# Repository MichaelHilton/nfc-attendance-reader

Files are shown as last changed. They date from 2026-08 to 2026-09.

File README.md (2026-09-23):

# NFC Attendance Reader

A classroom attendance reader: students tap their 13.56 MHz university ID card on a
desktop device, which shows their name, beeps, and logs attendance to an SD card.
Registration and grading happen on the instructor's laptop. Card numbers are never
stored in plain text, and there's no cloud service involved -- everything stays on
the device's SD card and your laptop.

Built for a Canvas classroom, but the pieces are separable: the reader/registration
system has no LMS dependency, and only `software/build_gradebook.py` knows about
Canvas specifically (see `docs/DESIGN_NOTES.md` Section 7).

## Hardware
- **ESP32-3248S035C** ("Cheap Yellow Display" / CYD, 3.5" ST7796 screen, WiFi, SD)
- **PN532** NFC reader over I2C (CN1: 3V3, GND, SDA=IO21, SCL=IO22; DIP switches = I2C)
- 20 mm speaker on the SPEAK connector (GPIO26)
- LiPo battery + USB-C charge/boost module (V713), power switch, all in a 3D-printed case
- Registration reader (laptop): a USB keyboard-wedge NFC reader that types the card number

## Folder layout
- **case/** — 3D-printable enclosure
  - `case_body.stl`, `case_lid.stl`, `case_stand.stl` — print these (PLA/PETG, 0.2 mm, no supports)
  - `case_gen.py` — parametric source (all dimensions at the top; regenerates the STLs)
  - `case_notes.md` — assembly, wiring, print settings, and every adjustable parameter
- **firmware/** — Arduino sketches for the CYD
  - `attendance_reader_PN532/` — the main sketch (open this folder in Arduino IDE)
  - `diagnostics/` — `i2c_scan`, `pn532_test`, `speaker_test` for bring-up/troubleshooting
  - `setup-arduino.sh` / `flash.sh` — install arduino-cli + the ESP32 core, then compile/flash from the command line
- **software/** — laptop-side Python (needs `pip install cryptography pyserial`)
  - `attendance_crypto.py` — shared crypto (keys, tokens, name encryption)
  - `register_cards.py` — registration station GUI → builds encrypted `roster.csv`, and appends each new card to `registration_log.csv`
  - `decode_attendance.py` — turns logged tokens back into AndrewIDs
  - `build_gradebook.py` — fills a Canvas attendance column (Present/Late/Absent) from the log
  - `recover_sessions.py` — dates the `unsynced-<millis>` rows of a log whose clock never synced
  - `reader_test.py` — shows exactly what the USB registration reader types
  - `sd_download.py` — pulls `attendance.csv`/`roster.csv` off the device over USB serial
  - `sd_upload.py` — pushes a new `roster.csv` to the device over USB serial (no SD card removal)
  - `aliases.csv` (copy from `aliases.csv.example`) — `typed_value,sis_login_id` fixups for AndrewIDs/names that don't match Canvas
  - `serial_bridge_host.sh` / `serial_bridge.sh` — bridge the board's USB serial port into the dev container (`SERIAL_BRIDGE.md`)

## How the pieces fit
1. **Generate the key (once):** `python3 software/attendance_crypto.py` → creates
   `secret.key` (keep private!) and writes `secret_key.h` straight into
   `firmware/attendance_reader_PN532/` — nothing to paste, and it's gitignored.
2. **Flash the device:** copy `wifi_config.h.example` to `wifi_config.h` in that same
   folder and fill in your network, then upload the sketch. The Serial Monitor should
   print `crypto self-test: HMAC OK, AES OK`.
3. **Register students:** `python3 software/register_cards.py` — each student taps and
   types their AndrewID (2-8 characters) → writes `roster.csv` (only `token,encrypted_name`)
   and logs when each new card was registered in `registration_log.csv`. Get it onto the
   device either by copying the file to the SD card, or — with the device still plugged
   in — `python3 software/sd_upload.py roster.csv` (sends it over USB; the device swaps
   it in and reloads without a reboot).
4. **In class:** the device reads cards, shows the AndrewID, logs `timestamp,token` to the SD
   (WiFi sets the clock over NTP; no cloud).
5. **Grade:** pull the log with `sd_download.py`, then run `build_gradebook.py` with the
   session date/time and the Canvas column to fill — it matches each AndrewID to a Canvas
   student by SIS Login ID and writes a Canvas-importable CSV (Present/Late/Absent,
   absent = 0). Students who registered a card that day but never tapped are credited
   from their registration time. `decode_attendance.py` gives a plain AndrewID+times list
   if you just want to read the log. If the clock never synced (every row
   `unsynced-…`), date the rows first with `recover_sessions.py` (TESTING_GUIDE Step 7).

Example gradebook run:
```
python3 software/build_gradebook.py --canvas Grades.csv --attendance attendance.csv \
    --date 2026-08-25 --start 10:00 --late-after 10 --close 30 --late-frac 0.5 \
    --column "Aug 25 Activity"
```
AndrewIDs match Canvas students by SIS Login ID. Anything that still doesn't match
is reported; pin it once in `aliases.csv` (`typed_value,sis_login_id`) and re-run.

## Dev container vs. host
The repo ships a dev container with the Python deps, arduino-cli and a browser
desktop (noVNC on forwarded port **6080**, password `vscode`) for running
`register_cards.py`. The container **can't see USB**, so flashing and the serial
tools (`sd_download.py`, `sd_upload.py`, `reader_test.py`) run on the host in a
virtualenv at `software/path/to/venv`, or go through the TCP serial bridge in
`software/SERIAL_BRIDGE.md`. Setup and a full "where does each command run" table
are in `docs/TESTING_GUIDE.md` Step 0.

## Security model
- Card numbers are **never** written to disk — only `token = HMAC-SHA256(key, id)`.
- The AndrewID is **AES-256 encrypted**; the device decrypts to display, the SD holds only ciphertext.
- The key lives in the firmware + `secret.key` on your laptop — never on the SD or in the cloud.
- Protects against a lost SD card / copied files. Does not, by itself, stop someone
  dumping the ESP32 flash (that would need flash-encryption + secure-boot).

## Documentation
- `TESTING.md` — how to run the automated test suite (`pytest`) and what each
  test protects; `docs/TESTING_PLAN.md` is the strategy behind it.
- `docs/TESTING_GUIDE.md` — step-by-step walkthrough, key → firmware → register →
  tap → download → gradebook, plus host/container setup, upload troubleshooting, and
  recovering an unsynced log.
- `software/SERIAL_BRIDGE.md` — using the board's serial port from inside the dev container.
- `docs/DESIGN_NOTES.md` — why it's built this way: hardware choices, the card-ID
  format quirks, firmware gotchas, case design, security model, gradebook logic.
- `docs/WIRING.md` — pin-by-pin PN532/SD/speaker connections.
- `docs/BOM.md` — parts list.
- `docs/ROADMAP.md` — current status, known issues, optional hardening.
- `case/case_notes.md` — case assembly and every adjustable print parameter.

## Status
Complete and tested end-to-end: case, firmware (with encryption + NTP, no cloud),
registration, decoding, and Canvas gradebook filling. In use in class, with one open
issue: **the reader isn't yet getting WiFi/NTP in the classroom**, so logs come off
unsynced and are dated with `recover_sessions.py`. The firmware has temporary serial
diagnostics for this (see `docs/ROADMAP.md`). Optional future hardening: ESP32
flash-encryption + secure-boot (see `docs/DESIGN_NOTES.md` Section 6).

## License
MIT — see `LICENSE`. Contributions welcome; see `CONTRIBUTING.md`.

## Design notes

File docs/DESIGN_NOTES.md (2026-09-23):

# Design Notes, Decisions & Lessons Learned

A running record of *why* this project is built the way it is — the dead ends, the
gotchas, and the decisions behind them. The `README.md` covers how to use everything;
this doc is the reasoning and the hard-won lessons. Newest context is folded in
throughout.

---

## 1. Hardware choices

**Controller — ESP32-3248S035C ("Cheap Yellow Display" / CYD, 3.5").**
Chosen because it bundles what the project needs on one cheap board: an ESP32-WROOM-32,
a 3.5" ST7796 touchscreen, WiFi, and a microSD slot, with a built-in rechargeable-battery
path via VIN. Key facts that bit us or mattered later:
- It's an **ESP32-WROOM-32**, *not* an S3 — 4 MB flash, **no PSRAM**, and a **CH340**
  USB-serial chip. The CH340 is why upload speed matters (below).
- Real board dimensions (from the datasheet, measured): **101.5 × 54.9 × 1.6 mm**, with
  ~5 mm of component height on the back and an **85 × 55 mm** glass area. Our first case
  used a wrong width (85.5 mm) and didn't fit — always use the datasheet numbers.
- Free GPIO is scarce; the speaker amp is on **GPIO26**, and the reader uses the **CN1**
  I2C header (**SDA=IO21, SCL=IO22**).

**Reader — PN532 (13.56 MHz NFC), not 125 kHz.**
The whole reason we're on 13.56 MHz: the CMU ID cards are **13.56 MHz**. This was
confirmed with NFC Tools on a phone (same serial twice) and by the card's 7-byte UID.
A 125 kHz reader cannot read these cards. We do **not** use the fobs. The PN532 talks
**I2C** (set its DIP switches to I2C).

**Registration reader — USB keyboard-wedge (BlissKiss, Amazon B0FJ1X7QFJ).**
Despite an online listing describing it as 125 kHz, the actual unit **does read our
13.56 MHz cards**. It acts like a keyboard: on a tap it "types" a number and presses Enter.

---

## 2. The card-ID format saga (important)

The device (PN532) reads the full **7-byte UID**. Example card: `04 95 AA 3A CF 22 90`.

The USB registration reader types **`0984257796`** for that same card. Decoding that:
`0984257796` = `0x3AAA9504` = the **first 4 UID bytes, little-endian** (`04 95 AA 3A` →
`3A AA 95 04`), as a zero-padded 10-digit decimal.

So the two devices see the same card differently. You **cannot** rebuild the full 7-byte
hex from 4 bytes, so we made the **firmware match the reader**: `uidToKey()` takes the
first 4 UID bytes, little-endian, and formats `%010lu`. Both sides now produce the
identical id string, so registration and reading line up. Using 4 bytes is plenty unique
for a class.

**Lesson:** whenever a second reader is involved, test what it actually emits
(`software/reader_test.py`) before assuming a format. The fix was to standardize on the
constrained device's output.

---

## 3. Firmware architecture & gotchas

- **Upload reliability (CH340):** set **Upload Speed = 115200** in the Arduino IDE.
  921600 fails intermittently on the CH340 ("failed to connect / verify flash").
- **Use the Upload arrow, not Debug.** Hitting Debug triggers OpenOCD and an FTDI error.
- **Pick the right port:** `/dev/cu.usbserial-…`, *not* `/dev/cu.debug-console`. Install
  the **CH340 driver** on macOS if the port doesn't appear.
- **PN532 bring-up is flaky right after a reset.** The fix that made it reliable: a
  **retry loop** (call `getFirmwareVersion()` up to ~12× with short delays) before giving
  up, and use `readPassiveTargetID(…, 300)` with a timeout. Removing
  `setPassiveActivationRetries` fixed reads that stopped after the first card.
- **Screen orientation:** the board is mounted **rotated 180°** so the USB cable exits
  low (less strain), so the sketch sets **`tft.setRotation(3)`** to flip the display back.
- **Non-blocking design:** the UI redraws only the center text band (`drawStatus`) and a
  millis timer clears the result (no `delay`), so scanning never stalls.
- **Time & no cloud:** the Google Apps Script upload was removed. WiFi now exists **only to
  set the clock via NTP** (`configTzTime`, TZ = US Eastern). Each tap logs a real local
  `timestamp,token`; before the clock syncs, rows are logged `unsynced-<millis>` and the
  gradebook script skips/flags them.
- **WiFi bring-up diagnostics (temporary).** Because the classroom WiFi hasn't
  connected yet, the sketch has a `DEBUG` block (`wifiScanReport()` at boot,
  `wifiDiagTick()` in `loop()`) that prints visible networks and the WiFi/NTP status
  over serial. The ESP32 is **2.4 GHz only**, so a 5 GHz-only network or an iPhone
  hotspot without *Maximize Compatibility* shows as `NO_SSID_AVAIL`. Remove the block
  once WiFi works.
- **Two different CSV files, don't confuse them:** `roster.csv` (the id/token → name
  lookup you build) vs `attendance.csv` (the log the device writes). Editing the wrong
  one is an easy mistake — names come from **roster.csv**.
- **Diagnostics exist for a reason:** `firmware/diagnostics/i2c_scan` (PN532 should appear
  at `0x24`), `pn532_test`, and `speaker_test` isolate wiring/library problems fast.
- **Library note:** the reader uses **Adafruit PN532 + Adafruit BusIO**. An earlier
  RDM6300 approach was abandoned (wrong frequency; its library wasn't in Library Manager).

---

## 4. Case design (parametric, `case/case_gen.py`)

The case is generated in Python (trimesh + manifold3d + shapely), not OpenSCAD (not
available in our tooling). Every dimension is a variable at the top of `case_gen.py`;
re-run it to regenerate the three STLs. `case_notes.md` lists all adjustables.

Hard-won lessons:
- **Print orientation drives everything.** The body prints **front-face-down** for a crisp
  bezel. That means *every feature on the front face is a recess that must bridge*. A big
  recess sags.
  - The original **"TAP" marker was a 34 mm filled recess** with raised letters floating
    in it → the floor bridged 34 mm and **sagged, melting into the letters**. Fixed by
    making the ring a **thin groove** and the **"TAP" text engraved** (debossed) — small
    bridges print clean. Paint-fill the engraving for contrast.
- **Mounting:** the glass **drops into the front opening** and rests on side lips; the PCB
  is held forward by that lip and backward by **four press-pads on the lid**. The lid is
  held by **four M3 screws** (2 top, 2 bottom) — an earlier snap lip was too fragile, so we
  raised the top blank strip (`top_bez`) to house the top screw bosses.
- **USB slot** went through several tries: wrong side, wrong size, then correct after
  accounting for the 180° board rotation → **bottom-left, sized ~13 × 8 mm** to clear a
  chunky cable boot.
- **PN532 pocket** sits in the tap zone behind the "TAP" ring, antenna facing out, held by
  snap clips + a wire notch. **Speaker** is a round pocket + round grille on the left with
  a wire gap in the ring.
- **Battery bay:** the back was deepened (`back_gap`) into a bay. The **LiPo tapes into a
  corral on the lid**, *not* against the board's back (avoids shorting/puncturing the pouch
  on the pins).

**Charge-module cradle — the fiddly part.** The V713 charge board is **30 × 20 × 4 mm**.
The tap-zone front is full (PN532 fills it; only ~28 mm free to its right — too narrow for
a 30 mm board), so the cradle went **on the lid** instead, in the lower half. It must stand
the board **upright (20 wide × 30 tall)** so the **USB-C short edge lines up with the
bottom-wall hole**. A **peek slot** in the lid shows the charge LEDs — they're in the
board's **top-right corner (1 mm from the right edge, 4–9 mm from the top)**, so mount the
board **LED-side toward the lid**.

**Power switch mounting.** The slide switch is **19 mm long, mounting holes 15 mm apart,
inline, 3 mm holes** → use **M2.5 self-tapping screws (~5–6 mm)** into the **1.9 mm printed
pilots** on two posts. The switch first **collided with a lid press-pad**; rather than move
the pad, we **centered the switch on the right edge between the two right-side pads**.

**General:** always dry-fit and check clearances against the *other* part (lid features vs
body features), since collisions only appear when assembled. Flat gray renders don't show
shallow relief — preview STLs in a slicer with lighting.

---

## 5. Power & charging

- Corded **USB-C charging** via the V713 module. Its pads: **"5V + / −" = OUTPUT**
  (→ CYD **VIN + GND** on the P1 header, through the switch); plain **"+ / −" = BATTERY**
  (→ LiPo). Verify with a multimeter before connecting the CYD (~5 V on the 5V pads,
  ~3.7–4.2 V on the battery pads).
- The **switch** is inline on the 5 V output (the budget module has no enable pin).
- **Charge from the bottom USB-C only** — that's the module. The CYD's own micro-USB (left
  edge) is the *programming* port and does not charge the battery.
- The module is a power-bank-style IC (has a boost inductor), so it generally charges while
  running; if it ever misbehaves plugged in, switch off and charge. **Never** feed the
  CYD's USB and VIN at the same time.
- Charge-status LEDs are inside — hence the lid peek slot (§4).

**TODO — on-screen battery indicator (not yet possible with this wiring).** The V713
module boosts the LiPo to a regulated ~5 V into `VIN`, so the ESP32 sees the same
voltage whether the cell is full or nearly flat — there is nothing to measure at
`VIN`, and the cheap module exposes no charge-status line. Adding a battery gauge to
the top status bar (`drawTopBar()` in the sketch) needs a hardware change, either:
  - a wire from the raw LiPo **+** through a 2×100 kΩ divider into a free **ADC1** GPIO
    (ADC2 is dead while WiFi is on; confirm a genuinely free ADC1 pin against the
    ESP32-3248S035C schematic — GPIO35 on the CN1/P3 header, input-only, is the usual
    candidate), then map ~3.3–4.2 V to a rough percentage (nonlinear, ±10–20%); or
  - a **MAX17048** I²C fuel gauge on the existing PN532 bus (IO21/IO22) for true
    state-of-charge, ~$5.
  Until one of those is added, the firmware deliberately has no battery UI.

---

## 6. Security design (keep card numbers out of plain text)

**The core insight:** "just encrypt the IDs" fails for two reasons at once — the device
must still *match* a tapped card (needs a deterministic transform), and card IDs are
low-entropy (~4 bytes), so any non-secret transform is brute-forceable in minutes. The
answer is a **secret key**:

- **`token = HMAC-SHA256(kmac, id)[:16]`** (32 hex chars). Deterministic so the device can
  match; one-way and not brute-forceable without the key. The **card number is never
  stored** — only its token.
- **Names = AES-256-CBC(kenc, name)** with a random IV, stored as `hex(iv+ciphertext)`.
  The device decrypts to show the name; the SD holds only ciphertext.
- **Subkeys:** `kmac = SHA256("MAC|"+K)`, `kenc = SHA256("ENC|"+K)` from one 32-byte master
  key `K`. `K` lives in the firmware (`SECRET_KEY[32]`) and in `secret.key` on the laptop —
  **never on the SD card or in the cloud.**
- **Cross-platform proof:** Python (`cryptography`/`hmac`) must match the ESP32's mbedTLS
  byte-for-byte. A **boot self-test** on the device uses a fixed vector (key `00..1f`,
  id `0984257796` → token `f989b34da0e80527fc371aabb3ac7402`, and a known encrypted
  "Michael Hilton") and prints `HMAC OK / AES OK`.
- **Files:** `roster.csv` = `token,encrypted_name`; `attendance.csv` = `timestamp,token`.
  The laptop decoder (`decode_attendance.py`) turns tokens back into names.

**Threat model (chosen):** protect against a **lost SD card / copied files** — both become
gibberish without the key. It does **not** stop someone who dumps the ESP32 flash to
extract the key; closing that needs **flash-encryption + secure-boot** (a separate,
larger effort we deferred).

**Decisions made:** device shows the **full (encrypted) name**; the cloud/attendance log
is **tokens only**; **name length ≤ 39 chars** (device buffer).

---

## 7. Gradebook / Canvas integration (implemented)

Goal: an instructor script that fills a **Canvas gradebook** (see the attached export
format) from the attendance data. Canvas CSV structure: `Student, ID, SIS User ID,
SIS Login ID, Root Account, Section`, then assignment columns named `Name (id)`, a
**`Points Possible`** row, and read-only score columns. ~92 students. Attendance is one of
the `1.00`-point activity columns.

Decisions:
- **Cut the Google Apps Script / cloud entirely.** The device just logs to SD.
- **Add NTP** to the firmware (WiFi stays only to set the clock) so each tap is timestamped
  → the script can group by day and compute lateness.
- **Matching:** students **type their AndrewID** (2-8 chars) at registration; the script
  matches it → Canvas **`SIS Login ID`** by local-part (exact, case-insensitive). Older
  rosters that stored a typed name still fall back to name normalization (case, punctuation,
  name order). An **`aliases.csv`** pins oddballs once (`typed_value → SIS Login ID`), and
  an **unmatched report** each run (nothing is silently dropped). We chose *not* to add
  roster autocomplete.
- **Scoring: Present / Late / Absent tiers.** On-time within a window → full points; within
  a later window → partial; otherwise **absent = explicit 0**. Windows/points are per-run
  parameters.
- Output: a **Canvas-importable CSV** (identity columns preserved, one attendance column
  filled) + a summary.

**Implemented in `software/build_gradebook.py`** and tested against the real Canvas export
with a synthetic roster/log. Behavior confirmed: exact and approximate ("Last, First" ↔
"First M Last") name matching, `aliases.csv` overrides, earliest-tap-per-student, on-time
vs late vs after-close scoring, absent = 0, and correct reporting of unmatched names,
unregistered cards, unsynced rows, and wrong-date taps — with every output row keeping the
exact Canvas column count so the file re-imports cleanly.

Matching order per tapped name: (1) `aliases.csv` → SIS Login ID, (2) exact normalized
name, (3) unique subset match (handles middle initials), else reported as unmatched or
ambiguous. Taps after `--close` are scored absent (0). Run it per session with `--date`,
`--start`, `--column`, and the late-window flags.

**Registration counts as a tap (added after first classroom use).** Students were
registered in class before the reader was set up, so they never tapped and were
marked absent. `roster.csv` can't say when a card was registered: it's rewritten in
full, sorted, on every save. So `register_cards.py` now appends
`timestamp,token` to `registration_log.csv` for each *new* card (not updates), and
`build_gradebook.py --registration-log` uses a same-day registration as the tap time
**only when the student has no real tap**. It still goes through the normal
present/late/absent windows, and the report lists who was credited. The log holds only
tokens, the same as `attendance.csv`.

**Canvas header quirk.** Some exports insert a posting-policy row (`Manual Posting`)
between the header and `Points Possible`. The script now finds `Points Possible` by
its label (falling back to row 2) instead of by position. Student rows are still
"has an `@` in SIS Login ID" (see ROADMAP).

**Card taps in the AndrewID box.** The wedge reader types wherever focus is, so a
second tap during the AndrewID prompt used to save the card number as the AndrewID.
All-digit input is now rejected: every AndrewID has a letter.

---

## 7a. Recovering logs whose clock never synced

In practice the reader has run whole class sessions without NTP, so every row is
`unsynced-<millis since boot>`. `software/recover_sessions.py` turns those back into
dated rows:

- **Session = one power-on.** Boot resets `millis` to ~0 and drops the synced clock,
  so a boundary is `millis` going backwards, or a real timestamp followed by an
  `unsynced-` row. (Unsynced→synced is *not* a boundary: NTP arriving mid-run doesn't
  reset `millis`.)
- **Dates are supplied by hand** (`--map N=YYYY-MM-DD`). The script prints one line per
  session (taps, distinct cards, span, any synced timestamps) to help. Session size and
  duration make real classes obvious next to one-card test runs.
- **Time of day = time since the session's first tap.** The first tap becomes `00:00:00`
  and the gradebook is run with `--start 00:00`. This assumes the reader was switched on
  at about class start. On the one day we could check (2026-08-28), the reboot that
  started class landed within ~5 min of the last synced timestamp. If it's switched on
  early, lateness shifts by that amount.
- **Torn SD writes.** Real logs contained a NUL-padded timestamp and truncated tokens.
  Those rows are reported and dropped. A garbled timestamp would otherwise read as
  "synced" and falsely split a session.

---

## 8. Quick "if I forget" checklist
- Regenerate `secret.key` (writes `secret_key.h` into the firmware folder automatically) → re-flash → confirm `HMAC OK / AES OK`.
- roster.csv holds **tokens + ciphertext** only; never plain ids/names.
- Print body/lid/stand **face/plate down, no supports**; check "TAP" and the peek slot in
  the slicer.
- Charge via the **bottom USB-C**; program via the **CYD micro-USB**; never both powered at once.
- If names don't show on a tap: it's a **roster.csv** problem (format/key mismatch), and
  check the boot self-test printed OK.

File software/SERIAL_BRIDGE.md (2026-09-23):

# Using the reader's serial port from inside the dev container

The board's USB serial port (`/dev/cu.usbserial-*` on macOS, `/dev/ttyUSB*` on
Linux) belongs to the **host**. Docker Desktop on macOS/Windows runs the
container inside a Linux VM and does **not** forward USB devices, so there is no
`devcontainer.json` setting that makes the port appear inside the container.

The simplest alternative is to run the serial tools on the host itself, from the
host virtualenv (`software/path/to/venv`, see `docs/TESTING_GUIDE.md` Step 0).
If you'd rather stay in the container, bridge the port over TCP with `socat`:

```
host machine                          dev container
-----------                          -------------
board  <--USB-->  serial_bridge_host.sh  <--TCP 9600-->  serial_bridge.sh  -->  ./reader-port (PTY)
                                                                                     |
                                                                          python3 sd_download.py --port ./reader-port
```

## One-time setup

- **Host:** install socat — macOS `brew install socat`, Debian/Ubuntu `sudo apt install socat`.
- **Container:** socat is installed by `postCreateCommand`. After pulling this
  change, run **Dev Containers: Rebuild Container** once. (Or just
  `sudo apt-get install -y socat` in the running container.)

## Each session

1. **On the host**, from `software/`:
   ```
   ./serial_bridge_host.sh                       # auto-detect port
   ./serial_bridge_host.sh /dev/cu.usbserial-XXXX 115200 9600
   ```
   Leave it running. Opening the port resets the ESP32 once — that's expected.
   Close the Arduino Serial Monitor first; only one program can hold the port.

2. **In the container**, from `software/`:
   ```
   ./serial_bridge.sh &                          # creates ./reader-port
   ```

3. **Run the tools**, always passing `--port` (auto-detect can't see the PTY):
   ```
   python3 sd_download.py --port ./reader-port --cmd roster
   python3 sd_upload.py roster.csv --port ./reader-port
   python3 reader_test.py --port ./reader-port
   ```

## Limitations

- **Firmware flashing does not work through this bridge.** `esptool` needs to
  toggle the DTR/RTS lines for the ESP32 boot sequence, and `socat` does not
  forward modem control lines. Flash `attendance_reader_PN532.ino` from the host
  (Arduino IDE / `arduino-cli`).
- If the container can't reach `host.docker.internal`, pass the host's LAN IP as
  the first argument to `serial_bridge.sh`.

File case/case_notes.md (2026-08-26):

# 3D-Printed Desk Case — Attendance Reader (CYD + PN532)

Rebuilt for the **PN532** reader (all-in-one board with a built-in antenna), replacing the old RDM6300 coil + reader corral with a single pocket. Three printed parts: **body**, **lid**, **stand**.

## The design in one look
- **The whole display glass (85 × 55 mm) drops into the front opening**, resting on the 8 mm left/right lips — captured with no pegs.
- **Board held** by the front lip (forward) + four **press-pads on the lid** (backward). The board slides in from the back; the lid ledge is only on the top/bottom walls so the 101.5 mm board clears the sides.
- **Lid retention:** **four screws** — two at the bottom and two at the top (there's now a taller blank strip above the screen to house the top bosses), so the back is held securely all around.
- **PN532 pocket** in the tap zone: a single recessed pocket (~43 × 41 mm) holds the reader flat against the front wall, antenna facing out, behind the "tap here" ring. Two snap clips hold it; a wire notch routes its cable up to CN1.
- **Speaker pocket** to the left of the PN532 — a **round pocket for a Ø20 mm speaker** with a **round sound grille** (center + ring of holes) through the front face, and a **1 cm gap in the ring wall** (top) for the speaker leads.
- **"TAP" label** engraved (debossed) into the front, ringed by a thin groove — both shallow so they print cleanly with the front face on the bed (no big recess to bridge/sag).
- **USB slot** on the **bottom-left edge, 13 mm up from the bottom**, sized **~13 × 8 mm to clear a chunky cable boot** — the board mounts **rotated 180°** so the cable exits low (less wire strain). Set **`tft.setRotation(3)`** in the sketch so the screen isn't upside down.
- Case ~108 × 119 × **25 mm** — deepened to add a **battery bay behind the board** for the LiPo + USB‑C charge/boost module. Rounded outer vertical corners (4 mm radius).
- **Charging:** the 30 × 20 mm charge board sits in a **cradle on the lid** (lower half, below the battery), USB‑C facing a **slot in the bottom wall**. The **power switch** mounts on the **right wall** — actuator through a slot, held by **two screw posts 15 mm apart** that its tiny screws thread into.
- **Battery mounting:** the LiPo tapes into a **shallow corral on the lid** (upper half; a wire gap lets the leads out) — **not** against the board's back, to avoid shorting/puncturing the pouch on the pins. The charge board sits in its own **lid cradle** just below the battery, so both share the lid and their wires stay short.

## Files
- `case_body.stl` — front enclosure: display opening, PN532 pocket + clips, USB slot, tap ring
- `case_lid.stl` — recessed back cover: 4 board press-pads, vents, screw holes
- `case_stand.stl` — desk cradle (~120 × 51 × 71 mm), reclines ~18°
- `case_gen.py` — parametric source (all dimensions at the top)

## Print settings
- PLA or PETG · 0.2 mm layers · 3 walls · 15–20 % infill · **no supports**
- Body & stand base **down**; lid plate **down** (pads point up).
- ~190 g filament total.

## Assembly
1. **PN532:** press it into the front pocket, **antenna side facing the front wall** (behind the tap ring). The two snap clips hold it; a dab of foam tape is a fine backup. Route its 4-wire cable out the pocket notch.
1b. **Speaker:** set it (cone toward the front) into the pocket behind the grille, over on the left; a bit of foam tape holds it. Plug it into the board's SPEAK connector.
2. **Wire to CN1:** one JST 1.25 mm cable — VCC→3V3, GND→GND, SDA→IO21, SCL→IO22. Guide it up through the wire keeper to the board's CN1 socket. Set the PN532 DIP switches to **I2C**.
3. **Display:** slide the CYD in from the back — glass through the front opening, PCB resting on the left/right lips, screen facing out.
4. **Close:** set the lid into the recessed seat and drive **four M3 × 8–10 mm screws** through the lid into the corner bosses (2 top, 2 bottom). The press-pads clamp the board forward.
5. **Stand:** set the unit into the cradle — bottom edge behind the front lip, back on the support.

## Adjustables (top of `case_gen.py`)
- `PN_W` / `PN_H` / `PN_T` — PN532 board size (measure yours; defaults 43 × 41 × 1.6 mm).
- `BL` / `BW` / `comp_h` — display board size and component height.
- `GW` / `GH` / `GDX` — glass size and offset.
- `USB_FROMBOT` / `USB_LEN` / `USB_TALL` — USB slot position/size (now bottom-left).
- `SPK_DIA` / `SPK_T` — round speaker diameter/thickness (default Ø20 × 5 mm); adjust to your speaker.
- `clr` — board-to-wall clearance; `recline` — stand angle; `back_gap` — **battery-bay depth** (raise for a thicker cell).
- `MOD_L` / `MOD_H` / `MOD_T` — charge-board size (now **30 × 20 × 4 mm**); the lid cradle and bottom USB‑C slot both key off these.
- `sw_cy` — switch center height on the right wall; the two screw posts sit ±7.5 mm from it (15 mm apart). `sw_pilots` = pilot-hole size for the screws.
- `usbc` / `psw` boxes — the **USB‑C charge slot** (bottom wall) and **switch actuator slot** (right wall); move to match your parts.
- `BAT_W` / `BAT_H` — battery corral size on the lid (default 55 × 40 mm); **measure your cell and adjust** so it nests snugly.

## Battery wiring (corded USB‑C charging)
- LiPo → charge module BAT (JST‑PH 2.0). Module **USB‑C** faces the bottom cutout.
- Module **5 V out → CYD `VIN` + `GND`** on the P1 connector (4‑pin JST 1.25, use only VIN + GND).
- **Switch** inline on the 5 V line (budget board has no EN pin), poking through the right slot.
- Don't power from USB and VIN at once — run off the battery/VIN path.
- `pad_short` / `pad_short_L` — how much to shorten the lid press-pads (base / far side); increase if they bottom out.
- corner radius: the `4.0` in `rrect_prism(out_w,out_h,out_d,4.0)` — bump up for rounder corners.

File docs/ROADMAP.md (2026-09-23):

# Roadmap & Known Issues

Current status of the project: what's built and verified, what's still open, and
optional hardening someone could pick up. See `DESIGN_NOTES.md` §7 for the
reasoning behind the gradebook decisions.

---

## Done

- **Firmware — cloud removed, NTP added.**
  `attendance_reader_PN532.ino` no longer has the Google Apps Script upload. WiFi
  is used only to set the clock via `configTzTime` (US Eastern). Each tap logs a
  real local `timestamp,token`; before the clock syncs, rows are written
  `unsynced-<millis>` and the gradebook skips/flags them.
- **`software/build_gradebook.py` — written and verified.**
  Decrypts the roster, matches each AndrewID to Canvas by SIS Login ID local-part
  (alias first; then, for older name-based rosters, exact normalized and
  unique-subset for middle initials), scores
  Present/Late/Absent per session (`--date --start --late-after --close
  --late-frac --column`), absent = 0, and writes a Canvas-importable CSV plus a
  clear report of unmatched names, unregistered cards, and unsynced rows.
  Confirmed end-to-end against synthetic fixtures: every scoring tier, alias
  resolution, and each flag behaves correctly, and only the target column is
  changed. The firmware timestamp format and the gradebook parser agree exactly.
- **Secrets hygiene.**
  WiFi credentials *and* the crypto key are both out of the tracked sketch now.
  `wifi_config.h` and the new `secret_key.h` live beside the `.ino`, uncommitted,
  and are pulled in via `#if __has_include` with placeholder fallbacks so a
  fresh clone still compiles with neither present. `attendance_crypto.py` and
  `register_cards.py` write `secret_key.h` straight into the firmware folder —
  nothing gets hand-pasted into the sketch anymore. `.gitignore` covers
  `secret.key`, `wifi_config.h`, `secret_key.h`/`firmware_key.h`, real rosters/
  attendance logs/Canvas exports, and `software/.venv/`. `.example` templates
  (`wifi_config.h.example`, `aliases.csv.example`) ship so a clone is usable
  out of the box.
- **Registration log + crediting.** `register_cards.py` logs when each new card
  was registered (`registration_log.csv`). `build_gradebook.py` credits a student
  who registered that day but never tapped (DESIGN_NOTES §7).
- **Card-tap guard at registration.** An all-digit AndrewID (a second card tap
  typed into the prompt) is rejected instead of saved.
- **Unsynced-log recovery.** `recover_sessions.py` splits a log into power-on
  sessions, lists them, and dates them from a `--map` you supply (DESIGN_NOTES §7a).
- **Canvas `Manual Posting` row** before `Points Possible` is handled.
- **Dev-container tooling.** noVNC desktop for the registration GUI, TCP serial
  bridge (`software/SERIAL_BRIDGE.md`), `firmware/flash.sh` + `setup-arduino.sh`.
  A host-side venv (`software/path/to/venv`) covers what the container can't reach
  (TESTING_GUIDE Step 0).

---

## Left to do

- **Get WiFi/NTP working in the classroom (in progress).** The reader still logs
  `unsynced-` rows in class, and those are being dated after the fact with
  `recover_sessions.py`. The firmware carries temporary serial diagnostics
  (`wifiScanReport()` / `wifiDiagTick()`, marked `DEBUG`) to show why it isn't
  connecting. Likely causes: eduroam-style enterprise auth, or a 5 GHz-only
  network/hotspot. See TESTING_GUIDE "Known limitation".
- **Remove the WiFi debug block** from `attendance_reader_PN532.ino` (the two
  functions and their two call sites) once WiFi is confirmed.

- **Rotate the real key before any classroom use.** The `SECRET_KEY` that was
  briefly hardcoded directly in the tracked `.ino` (before the `secret_key.h`
  fix above) should be treated as burned even though it was never actually
  pushed anywhere. Run `python3 software/attendance_crypto.py` to generate a
  fresh `secret.key`/`secret_key.h`, re-flash, confirm the boot self-test still
  prints `crypto self-test: HMAC OK, AES OK`, and re-register cards under the
  new key (a roster built under the old key won't match).
- **Put your real network in `wifi_config.h`.** It currently holds the home
  network; set whatever WiFi the reader will use in class (needed only so NTP can
  set the clock).

---

## Optional / nice-to-have

- **Harden the Canvas student-row detection.** `Points Possible` is now found by
  its label, but student rows are still identified by an `@` in the SIS Login ID.
  If a real export ever puts a bare Andrew ID there (no `@`), it silently reports
  "0 enrolled" and marks everyone absent. Treating every non-blank row after
  `Points Possible` as a student would remove that assumption. (Not urgent:
  confirmed a non-issue for exports whose SIS Login ID is the full email.)
- **ESP32 flash-encryption + secure-boot.** The chosen threat model covers a lost
  SD card. Closing the "someone dumps the flash to extract the key" gap is a
  separate, larger effort, deferred by design (DESIGN_NOTES §6).

---

## Definition of done — met

- Device logs real local `timestamp,token`; no cloud code remains; boot self-test
  passes. ✓
- `build_gradebook.py` turns a day's log into a Canvas-importable CSV, scores
  Present/Late/Absent with absent = 0, and reports anything it couldn't place. ✓
- Verified end-to-end (synthetic). A real-card dry run with the rotated key is the
  last confirmation before relying on it in class.

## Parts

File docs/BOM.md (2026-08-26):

# Bill of Materials

Approximate -- fill in your own prices/links below (component pricing drifts and
varies by source; the placeholders mark where to drop in your own numbers).

| Part | Spec / model | Qty | Source | Approx. cost |
|---|---|-----|---|---|
| Display + microcontroller | ESP32-3248S035C ("Cheap Yellow Display" / CYD), 3.5" ST7796, WiFi, microSD slot | 1 | *(fill in)* | *(fill in)* |
| NFC reader | PN532 (13.56 MHz), I2C mode | 1 | *(fill in)* | *(fill in)* |
| Registration reader | USB keyboard-wedge NFC reader, 13.56 MHz (reference build used a BlissKiss unit, Amazon ASIN B0FJ1X7QFJ -- confirm 13.56 MHz support before buying, some listings are ambiguous) | 1 | *(fill in)* | *(fill in)* |
| microSD card | Any size sufficient for a semester's `attendance.csv` (a few MB is plenty) | 1 | *(fill in)* | *(fill in)* |
| Speaker | 8ohm, ~20 mm round (optional -- reader works silently without it) | 1 | *(fill in)* | *(fill in)* |
| NFC-compatible cards/tags | For testing without real ID cards -- any 13.56 MHz NFC card/tag works for bring-up | a few | *(fill in)* | *(fill in)* |
| 3D-printed case | See `case/` -- `case_body.stl`, `case_lid.stl`, `case_stand.stl` (PLA/PETG, ~190 g total) | 1 set | print yourself | filament cost only |
| Case screws | M3 x 8-10 mm (lid), M2.5 self-tapping (~5-6 mm, power switch) | ~6 | *(fill in)* | *(fill in)* |

## Optional -- battery-powered build

| Part | Spec / model | Qty | Source | Approx. cost |
|---|---|-----|---|---|
| LiPo battery | Sized to fit the case battery bay (default corral ~55 x 40 mm -- measure your cell) | 1 | *(fill in)* | *(fill in)* |
| USB-C charge/boost module | "V713" or equivalent, ~30 x 20 x 4 mm | 1 | *(fill in)* | *(fill in)* |
| Slide power switch | 19 mm long, mounting holes 15 mm apart, inline, 3 mm holes | 1 | *(fill in)* | *(fill in)* |

## Notes

- Confirm your institution's ID cards are actually 13.56 MHz NFC before building --
  the reference deployment (CMU) uses 13.56 MHz cards; a 125 kHz reader will not
  read them. Check with a phone NFC-scanning app or the card's printed spec.
- `case/case_gen.py` is parametric -- if your PN532 board, speaker, or charge
  module differ in size, adjust the dimensions at the top of that file and
  regenerate the STLs rather than force-fitting the default case.

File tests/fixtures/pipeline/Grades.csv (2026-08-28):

Student | ID | SIS User ID | SIS Login ID | Root Account | Section | Aug 26 Activity (999001) | Aug 27 Activity (999002)
Points Possible |  |  |  |  |  | 1.00 | 2.00
Chen, Alice | 1001 | achen | alice.chen@example.edu | School | Section 1
Diaz, Bob | 1002 | bdiaz | bob.diaz@example.edu | School | Section 1
Osei, Cara | 1003 | cosei | cara.osei@example.edu | School | Section 1
Nguyen, David M | 1004 | dnguyen | david.nguyen@example.edu | School | Section 1
Park, Eun | 1005 | epark | eun.park@example.edu | School | Section 1

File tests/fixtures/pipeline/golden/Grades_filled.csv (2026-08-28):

Student | ID | SIS User ID | SIS Login ID | Root Account | Section | Aug 26 Activity (999001) | Aug 27 Activity (999002)
Points Possible |  |  |  |  |  | 1.00 | 2.00
Chen, Alice | 1001 | achen | alice.chen@example.edu | School | Section 1 |  | 2
Diaz, Bob | 1002 | bdiaz | bob.diaz@example.edu | School | Section 1 |  | 2
Osei, Cara | 1003 | cosei | cara.osei@example.edu | School | Section 1 |  | 1
Nguyen, David M | 1004 | dnguyen | david.nguyen@example.edu | School | Section 1 |  | 0
Park, Eun | 1005 | epark | eun.park@example.edu | School | Section 1 |  | 2

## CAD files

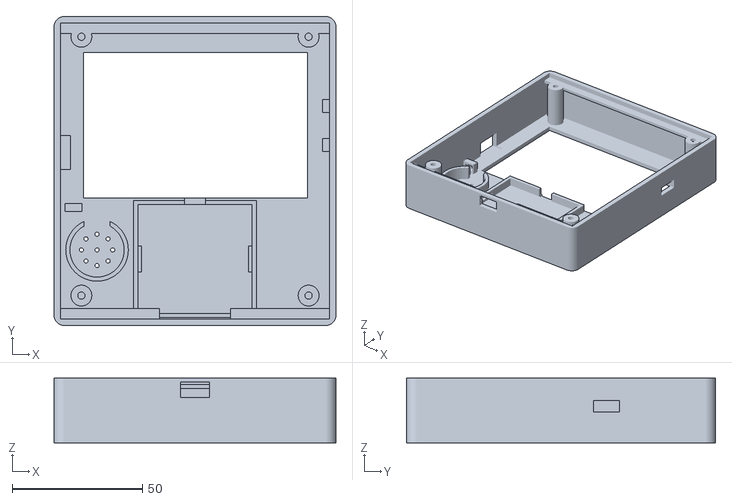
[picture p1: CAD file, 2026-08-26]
case/case_body.stl
108.1 x 118.5 x 24.8

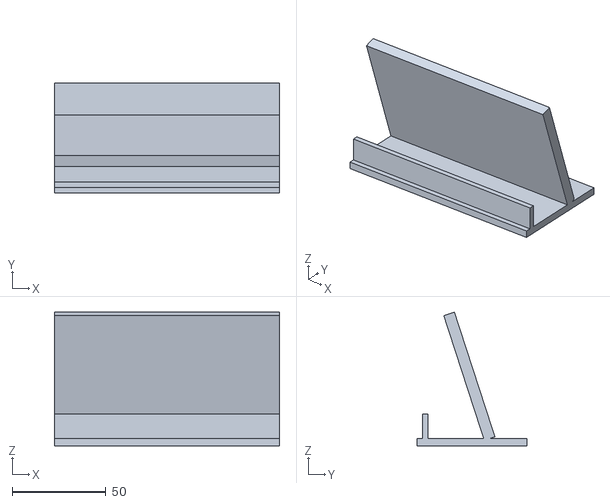
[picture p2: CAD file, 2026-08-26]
case/case_stand.stl
120.1 x 58.8 x 71.4

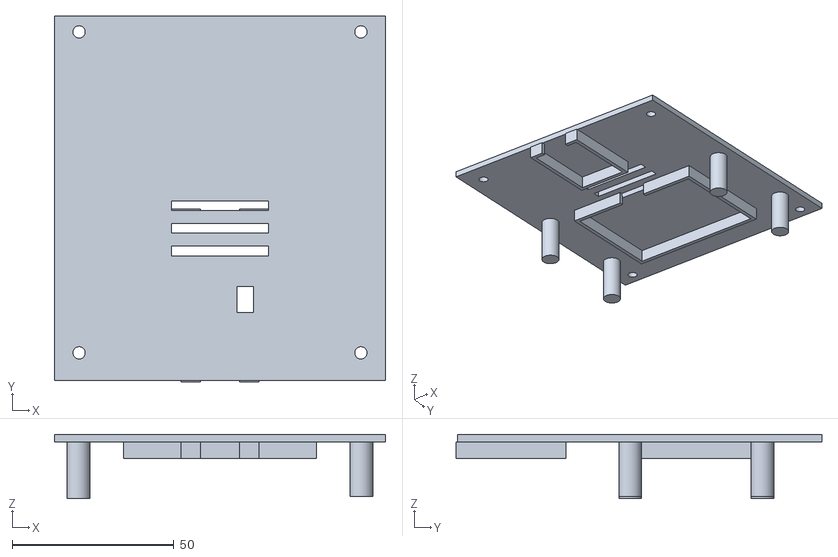
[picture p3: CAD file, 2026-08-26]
case/case_lid.stl
102.3 x 113.1 x 19.8

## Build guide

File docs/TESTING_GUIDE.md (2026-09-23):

# Attendance Reader — End-to-End Test Guide (from zero)

A step-by-step walkthrough for testing the whole system from a clean slate:
**key → firmware → register cards → tap in class → download log → gradebook.**

Everything laptop-side runs from the `software/` folder unless noted. The reader
plugs into the Mac over USB. Read **Step 0** first if you work in the dev container:
some commands have to run on the Mac itself.

The pipeline:

```
[1] generate key ──► [2] flash firmware ──► [3] register cards ──► roster.csv ─► SD
                                                                                  │
   Canvas CSV ◄── [6] build gradebook ◄── [5] download+decode ◄── [4] tap cards ◄┘
```

---

## Step 0 — Where to run what: dev container vs. host

The dev container can't see the Mac's USB ports (Docker Desktop doesn't forward
USB), so anything that talks to the board directly runs **on the host**:

| Runs on the **host** (Mac) | Runs anywhere (container or host) |
|---|---|
| `firmware/flash.sh` upload (container: `-n` compile only) | `attendance_crypto.py` (key generation) |
| Arduino IDE / `arduino-cli monitor` (Serial Monitor) | `register_cards.py`: in the container, use the browser desktop below |
| `sd_download.py`, `sd_upload.py`, `reader_test.py`, unless you use the serial bridge | `decode_attendance.py`, `build_gradebook.py`, `recover_sessions.py` |
| `software/serial_bridge_host.sh` (the host half of the bridge) | the test suite (`pytest`) |

**Host virtualenv.** The Mac's Homebrew Python is externally managed (PEP 668), so
the host-side scripts run from a virtualenv at `software/path/to/venv` (gitignored).
It only needs the runtime dependencies (`cryptography`, `pyserial`). One-time setup,
**on the host**, from `software/`:

```bash
cd software
python3 -m venv path/to/venv
path/to/venv/bin/pip install -r requirements.txt
```

After that, in each host terminal session:

```bash
cd software
source path/to/venv/bin/activate      # now `python3` has cryptography + pyserial
python3 sd_download.py
```

(or skip `activate` and call `path/to/venv/bin/python3 sd_download.py` directly).

This venv, like the repo-root `.venv/` (the host's test venv, see `TESTING.md`),
holds macOS binaries and **does not work inside the container**. That's expected.
The container doesn't need it: `postCreateCommand` installs `requirements-dev.txt`
into the container's own Python, so there you just run `python3 …`.

**Using the board from inside the container anyway.** Instead of switching to the
host, you can bridge the serial port into the container over TCP. See
`software/SERIAL_BRIDGE.md`. The bridge works for `sd_download.py`, `sd_upload.py`
and `reader_test.py`, but **not** for flashing.

**GUI in the container.** `register_cards.py` needs a display. The container runs
a lightweight desktop served over noVNC: open the forwarded port **6080** in a
browser (password `vscode`), open a terminal there, and run the script. The USB
registration reader "types" into whatever window has focus, so keep the noVNC
browser tab focused while students tap.

---

## Step 1 — Generate the key

Run once, from `software/`:

```bash
cd software
python3 attendance_crypto.py
```

This creates:
- `secret.key` — the 32-byte master key (**keep private**, never on SD or in git).
- `secret_key.h` — written directly into `firmware/attendance_reader_PN532/secret_key.h`.
  Nothing to paste — the sketch `#include`s it automatically when the file is present,
  and falls back to a placeholder key (compiles, but won't match a real roster) when
  it isn't.

It's **idempotent**: if `secret.key` already exists it's reused, not overwritten.
The run prints a roundtrip self-test (`roundtrip = <your test name>`) so you know the
crypto works.

Both `secret.key` and `secret_key.h` are gitignored — never commit either one, and
never copy them onto the SD card.

---

## Step 2 — Flash the firmware

Either the Arduino IDE (2a) or the `firmware/flash.sh` script (2a-alt). Flash from
the **host** the board is plugged into — USB flashing does not work through
`software/serial_bridge.sh`.

### 2a-alt. Scripted (arduino-cli)

One-time: `./firmware/setup-arduino.sh` (installs arduino-cli, the ESP32 core, and
the libraries; still needs a `User_Setup.h` for the 3.5" ST7796 CYD — see
`docs/DESIGN_NOTES.md`). The devcontainer installs arduino-cli on create, so there
you only need to run `setup-arduino.sh` once for the core + libraries.

```
./firmware/flash.sh            # auto-detect port, compile + upload
./firmware/flash.sh -n         # compile only (no board needed)
./firmware/flash.sh /dev/cu.usbserial-XXXX
```

Then confirm the boot output as in step 6 below. Inside the devcontainer only
`-n` works — the host USB port isn't visible to the container.

### 2a. Normal flow

1. Plug the CYD reader into the Mac with a **data** USB cable, **directly** (no hub/dock).
2. Open `firmware/attendance_reader_PN532/attendance_reader_PN532.ino` in Arduino IDE.
3. **Tools → Board**: the ESP32 board for the CYD (e.g. *ESP32 Dev Module*).
4. **Tools → Port**: select the `/dev/cu.usbserial-…` port.
5. Click **Upload**.
6. Open **Serial Monitor at 115200 baud** and confirm the boot lines:
   ```
   crypto self-test: HMAC OK, AES OK
   Serial commands: dump | roster | upload | count | help
   ```
   The screen should show **Ready** — green if an SD card is inserted, orange if not.
   The top bar shows the clock (`clock not set` until WiFi + NTP sync, then
   `YYYY-MM-DD HH:MM:SS`) on the left and `WiFi` / `no WiFi` on the right.

   The firmware currently also prints **temporary WiFi diagnostics** on the same
   serial port. At boot it lists every 2.4 GHz network it can see and flags whether
   your `WIFI_SSID` is among them. After that it prints the status every 2 s until
   WiFi and NTP are both up:
   ```
   [wifi] target SSID="MyNetwork"  pass length=12
   [wifi]   1) MyNetwork                        RSSI  -48  ch  6  secured   <-- MATCH
   [wifi] status=DISCONNECTED
   [wifi] CONNECTED  ip=172.20.10.3  gw=172.20.10.1  rssi=-47 dBm
   [ntp]  clock set: 2026-09-23 10:02:11
   ```
   `NO_SSID_AVAIL` means the network isn't visible (5 GHz-only, or a phone hotspot
   without *Maximize Compatibility*). `CONNECT_FAILED` usually means a wrong
   password. From the command line: `arduino-cli monitor -p <port> -c baudrate=115200`
   (on the host).

> The self-test uses a fixed test vector, so `HMAC OK, AES OK` proves the crypto
> engine works **regardless of which key is loaded**. The real-key match is proven
> later when a registered card shows the correct name (Step 4).

### 2b. If upload fails with `termios.error: (22, 'Invalid argument')`

This is a **serial-link / upload-speed problem**, not a code problem — the sketch
compiles (≈79% flash). The macOS CH340/CH9102 driver rejected the high upload baud,
and the port often drops off the USB bus afterward. Fix in this order:

1. **Reconnect cleanly.** Unplug the device, wait ~5 s, plug it back in — directly
   to the Mac, known-good **data** cable. Confirm the port reappears:
   ```bash
   ls /dev/cu.*
   ```
   You should see a `cu.usbserial-…` entry. If nothing appears, it's the cable
   or the CH34x driver (see 2c).
2. **Lower the upload speed** — this is the actual fix for the termios error:
   **Tools → Upload Speed → 115200** (down from 921600).
3. **Re-select the port** — **Tools → Port** — the name can change on replug, and
   a stale selection points at a port that no longer exists.
4. **Retry Upload.**
5. **If it still won't connect:** hold the **BOOT** button while the IDE prints
   `Connecting……`, release once it starts writing. Some CYD units need the manual
   boot handshake.

### 2c. If the port never appears (`ls /dev/cu.*` shows nothing)

- Try a different USB cable (many are charge-only) and a different Mac port.
- Confirm the CH34x/CH9102 driver is working. On recent macOS the driver is
  built in; if the device shows in *System Information → USB* but no `cu.usbserial`
  appears, install the WCH CH34x macOS driver and reboot.
- Test the raw port once it's back:
  ```bash
  python3 - <<'PY'
  import serial, glob
  ports = glob.glob("/dev/cu.usbserial*")
  print("ports:", ports)
  if ports:
      s = serial.Serial(ports[0], 115200, timeout=1); s.close(); print("opened OK")
  PY
  ```

---

## Step 3 — Register test cards

The registration reader is the **USB keyboard-wedge** NFC reader (it types the card
number + Enter) — *not* the CYD device.

1. From `software/`:
   ```bash
   cd software
   python3 register_cards.py
   ```
   A full-screen black window opens (green = ready, cyan = saved).
2. For each test student: **tap the card**, then **type the AndrewID** (2-8 characters)
   and press **Enter**. The AndrewID is AES-encrypted; only `token,enc` is written —
   the card number is never stored.
   - If the student taps **again** while the AndrewID prompt is up, the reader types
     the card number into the box. An all-digit entry is rejected ("That's a card tap,
     not an AndrewID"), so it can't be saved as an AndrewID. Just type the AndrewID.
   - Tapping an already-registered card and entering a new AndrewID **updates** that
     card (the screen shows the previous value).
3. Register at least **2 cards** so we can see present/absent behavior later.
4. Press **Esc** to quit. This produces:
   - `software/roster.csv`: `token,encrypted_andrewid`, rewritten in full on every save.
   - `software/registration_log.csv`: `timestamp,token`, one line appended per
     **new** card. This is the only record of *when* each card was registered.
     `build_gradebook.py` uses it to credit students who registered in class but
     never tapped the reader (Step 6). Keep it next to `roster.csv`. Both files are
     gitignored.
5. Get `roster.csv` onto the device, either:
   - **over USB** (device plugged in, no SD removal):
     `python3 sd_upload.py roster.csv` (host, or via the serial bridge). The device
     swaps it in and reloads without a reboot. Or:
   - **copy it to the SD card** (root of the card, filename `roster.csv`), re-insert
     the card, and power-cycle the reader.

   The screen should show `N in roster`.

> Optional sanity check of what the USB reader actually types:
> `python3 reader_test.py`, then tap a card.

---

## Step 4 — Tap cards "in class"

1. Power the reader with the roster SD card inserted (screen shows **Ready**,
   green, and `N in roster`).
2. Tap each registered card:
   - Known card → **name shown**, high ding, logged as `timestamp,token`.
   - Unknown card → **"Unknown / not registered"**, low buzz (still logged).
3. Confirm the on-screen name matches who you registered — **this is the real-key
   end-to-end proof** (roster built with `secret.key` == key flashed into firmware).
4. Timestamps come from WiFi/NTP. Before the clock syncs, rows are written
   `unsynced-<millis>` and are skipped by the gradebook. A simple home network
   (plain SSID + password) sets the clock fine; **many campus enterprise WiFi
   networks (eduroam and similar) won't work with `WiFi.begin(ssid, pass)`** —
   sort out classroom time-sync separately (see the cleanup note at the end).

---

## Step 5 — Download + decode the log

Close the Arduino **Serial Monitor first** (only one program can hold the port).
The `sd_*` commands run **on the host** in the host venv (Step 0) or through the
serial bridge.

1. Pull the log off the device over USB:
   ```bash
   cd software
   python3 sd_download.py                 # auto-detects port → attendance.csv
   # if auto-detect misses: python3 sd_download.py --port /dev/cu.usbserial-XXXX
   python3 sd_download.py --cmd count      # quick row count
   python3 sd_download.py --cmd roster     # pull roster.csv back for a check
   ```
   To push a **new** roster.csv to the device without pulling the SD card:
   ```bash
   python3 sd_upload.py roster.csv        # sends it over USB; device swaps it in and reloads
   python3 sd_download.py --cmd roster    # read it back to confirm
   ```
2. Decode tokens → names (laptop-only, uses `secret.key`):
   ```bash
   python3 decode_attendance.py            # attendance.csv + roster.csv here
   ```
   Output `attendance_decoded.csv` has `raw_time,name`. Every registered tap
   should show its name; unknown tokens show `UNKNOWN xxxxxxxx`.

---

## Step 6 — Build the Canvas gradebook

You need a **Canvas gradebook export CSV** (Canvas → Grades → Export) with the
attendance assignment column already created. No real course handy? Copy
`software/Grades.csv.example` to `Grades.csv` and try the command below as-is —
it's a fake 3-student roster shaped exactly like a real Canvas export.

```bash
cd software
python3 build_gradebook.py \
    --canvas Grades.csv \
    --attendance attendance.csv \
    --date 2026-08-25 --start 10:00 \
    --late-after 10 --close 30 --late-frac 0.5 \
    --column "Aug 25 Activity"
```

Scoring (per the earliest tap per student that day):
- tap ≤ `--late-after` min after start → **Present** (full points)
- ≤ `--close` min → **Late** (`--late-frac` × points)
- after `--close`, or never tapped → **Absent = 0**

It writes `Grades_filled.csv` (**only the one column changes**) and prints a report:
present/late/absent counts, plus any **unmatched IDs**, **ambiguous IDs**,
**unregistered cards**, and **unsynced taps**.

AndrewIDs match Canvas by the local-part of `SIS Login ID`. Fix anything that
still doesn't match once in `software/aliases.csv` (start from
`aliases.csv.example`):
```
typed_value,sis_login_id
jdoe,jdoe2@example.edu
```
then re-run. Import `Grades_filled.csv` back into Canvas.

**Students who registered but never tapped.** If `registration_log.csv` (from
Step 3) is in the working directory, a student with **no tap** on `--date` but a
card **registered that day** is scored from the registration time, using the same
present/late/absent windows. This covers registering students in class before the
reader was running. A real tap always takes priority. The report lists these
students (`N student(s) had no tap but registered a card this date…`). Point
elsewhere with `--registration-log PATH`. A missing file is fine (nothing is
credited).

**Canvas export quirks handled.** Some exports have an extra posting-policy row
(`Manual Posting`) between the header and `Points Possible`. That's detected
automatically. Student rows are still recognized by an `@` in `SIS Login ID`.

---

## Step 7 — Recovering a log whose clock never synced

If WiFi/NTP never connected, every row in `attendance.csv` is
`unsynced-<millis-since-boot>,token` and Step 6 scores no one (the report shows
them all as unsynced). `recover_sessions.py` gives those rows real dates:

1. **List the sessions.** Each power-on of the reader is one session (millis reset
   to ~0 at boot). Run it once without `--map`. It prints one line per session:
   ```bash
   python3 recover_sessions.py attendance.csv --out /dev/null
   ```
   ```
   session 5: 64 taps, 63 cards, lines 126-189, 37 min span  (unmapped)
   session 6: 1 taps, 1 cards, lines 190-190, 0 min span  (unmapped)
   session 9: 8 taps, 1 cards, lines 324-331, 2 min span, synced 2026-09-11 11:53:27 .. …
   ```
   A ~class-sized session lasting about a class period is a real class. A handful
   of taps from one card is a test.
   Rows with truncated tokens or garbled timestamps (from a torn SD write) are
   reported on stderr and dropped.
2. **Work out which date each session was.** Use the number of taps, who tapped,
   any nearby synced timestamps, and your class calendar. Power-ons that were just
   testing can simply be left unmapped.
3. **Map and write:**
   ```bash
   python3 recover_sessions.py attendance.csv \
       --map 5=2026-08-28 --map 7=2026-09-08 \
       --out attendance_recovered.csv
   ```
   It prints who was present on each recovered date. Synced rows are kept as-is,
   and unsynced rows in unmapped sessions are dropped.
4. **Grade each recovered date with `--start 00:00`.** A recovered tap's time of
   day is the time since that session's **first tap** (first tap = `00:00:00`).
   That assumes the reader was switched on at about class start:
   ```bash
   python3 build_gradebook.py --canvas Grades.csv --attendance attendance_recovered.csv \
       --date 2026-08-28 --start 00:00 --late-after 10 --close 30 --column "Aug 28 Activity"
   ```
   If the reader was switched on well before class, late/absent cutoffs will be
   off by that much. Sanity-check the printed lists before importing.

`attendance_recovered.csv` contains tokens only, but it's still student attendance
data. It's gitignored, like the other logs.

---

## Quick command reference

**Host** = run on the Mac in the host venv (`source path/to/venv/bin/activate`,
Step 0), or through the serial bridge.

| Task | Command (run from `software/`) | Where |
|---|---|---|
| Generate/inspect key | `python3 attendance_crypto.py` | anywhere |
| Flash firmware | `../firmware/flash.sh` (`-n` = compile only) | host (compile: anywhere) |
| Register cards | `python3 register_cards.py` | anywhere (container: noVNC, port 6080) |
| See what the USB reader types | `python3 reader_test.py` | host |
| List serial ports | `ls /dev/cu.*` | host |
| Push roster to device | `python3 sd_upload.py roster.csv` | host |
| Download attendance log | `python3 sd_download.py` | host |
| Count logged rows | `python3 sd_download.py --cmd count` | host |
| Decode log → names | `python3 decode_attendance.py` | anywhere |
| Build gradebook | `python3 build_gradebook.py --canvas … --date … --start … --column …` | anywhere |
| Date an unsynced log | `python3 recover_sessions.py attendance.csv --map N=YYYY-MM-DD` | anywhere |

Device serial commands (in Serial Monitor): `dump` · `roster` · `count` · `help`.

---

## Known limitation: classroom WiFi for NTP

**Status: not yet working in class.** Enterprise WiFi (eduroam and similar campus
networks) needs more than `WiFi.begin(ssid, pass)`, so the clock may not sync on
those networks. Options:

- A **phone hotspot** for the first minute (just to set the clock). On an iPhone,
  turn on *Personal Hotspot → Maximize Compatibility*: the ESP32 only has a
  2.4 GHz radio and won't see a 5 GHz-only hotspot. Put the hotspot's exact name
  in `WIFI_SSID`.
- A network that accepts a plain SSID + password.
- Accept `unsynced` rows and date them afterwards with `recover_sessions.py`
  (Step 7).

The serial diagnostics described in Step 2a show exactly which case you're in.

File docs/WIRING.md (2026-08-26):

# Wiring Reference

Pin assignments as used in `firmware/attendance_reader_PN532/attendance_reader_PN532.ino`.
If you deviate from the reference hardware, update the `#define`s near the top of the
sketch to match.

## PN532 NFC reader (I2C, via the CYD's CN1 header)

Set the PN532's DIP switches to **I2C** mode before wiring.

| PN532 pin | CYD pin |
|---|---|
| VCC | 3V3 |
| GND | GND |
| SDA | IO21 |
| SCL | IO22 |

IRQ is unused (the firmware polls; `PN532_IRQ` is set to `255`).

## microSD card (SPI, built into the CYD)

| Signal | GPIO |
|---|---|
| SCK | 18 |
| MISO | 19 |
| MOSI | 23 |
| CS | 5 |

## Speaker

An 8ohm speaker (the reference build uses a 20 mm round speaker) connects to the
board's **SPEAK** connector, driven from **GPIO26**. Optional -- the reader works
silently without one.

## Power (battery build only)

See `docs/DESIGN_NOTES.md` Section 5 for the full reasoning. In short:

- Charge module **5V output -> CYD `VIN` + `GND`** (P1 header), routed through the
  power switch.
- Charge module **battery pads -> LiPo** (JST-PH 2.0).
- Charge via the **bottom USB-C** (charge module) only -- the CYD's own micro-USB
  is the programming port and does not charge the battery. Never power both at once.

## Board reference

- **ESP32-3248S035C** ("Cheap Yellow Display" / CYD, 3.5" ST7796 screen) --
  ESP32-WROOM-32 (4 MB flash, no PSRAM), CH340 USB-serial.
- Registration station uses a separate **USB keyboard-wedge NFC reader** plugged
  into the instructor's laptop -- no GPIO wiring involved, it just types.

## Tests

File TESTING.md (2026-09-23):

# Testing

How to run the test suite and what each part of it is for. For the *why this
order* strategy and history, see `docs/TESTING_PLAN.md`. For the manual,
device-in-hand walkthrough, see `docs/TESTING_GUIDE.md`.

The suite is Python (`pytest`) and covers everything laptop-side in `software/`,
plus a contract check against the firmware crypto and an optional native compile
of it. No hardware is needed; a full run is ~2 seconds.

---

## Quick start

```bash
python3 -m venv .venv
.venv/bin/pip install -r requirements-dev.txt
.venv/bin/pytest
```

`requirements-dev.txt` pulls in the runtime deps (`cryptography`, `pyserial`)
plus `pytest` and `pytest-cov`. A repo-root `.venv/` is used because the system
Python is externally managed (PEP 668); it is gitignored.

**In the dev container**, skip the venv: `postCreateCommand` already installed
`requirements-dev.txt` into the container's Python, so run `python3 -m pytest`
(use it wherever this page says `.venv/bin/pytest`). A `.venv/` created on the Mac
holds macOS binaries and fails inside the container with
`cannot execute: required file not found`. That's expected, so leave it for the
host. (The separate `software/path/to/venv` is the host's *runtime* venv for the
serial tools. See `docs/TESTING_GUIDE.md` Step 0.)

Once the venv exists, just:

```bash
.venv/bin/pytest                 # everything
.venv/bin/pytest -q              # quieter
.venv/bin/pytest --cov           # with a coverage report (gate: 95%, see .coveragerc)
```

Config lives in `pyproject.toml` (`[tool.pytest.ini_options]`): tests are under
`tests/`, and `software/` is put on `sys.path` so tests can
`import attendance_crypto` the same way the scripts import each other.

---

## Running subsets

```bash
.venv/bin/pytest tests/test_gradebook_scoring.py          # one file
.venv/bin/pytest tests/test_gradebook_scoring.py::test_score_tap_tiers
.venv/bin/pytest -k "match or alias"                      # by name substring
.venv/bin/pytest -m "not slow"                            # skip the slow case regen
.venv/bin/pytest -rs                                      # show why anything skipped
```

### Markers

| Marker | Meaning | Runs when |
|---|---|---|
| `slow` | more than a second or two (the full `case_gen.py` regeneration) | always, unless `-m "not slow"` |
| `needs_mbedtls` | needs a C++ compiler **and** pre-4.x mbedTLS headers/libs | auto-skips otherwise |
| `needs_trimesh` | needs the `trimesh` / `manifold3d` / `shapely` / `matplotlib` stack | auto-skips otherwise |
| `hardware` | needs a physical reader / serial port | never in CI; not currently used by any test |

Nothing is silently missing: `-rs` prints a one-line reason for every skip.

---

## Optional suites

Two areas need extra tooling. They **skip cleanly** when it is absent, so a plain
`pytest` is always green.

### Native firmware-crypto check (`test_firmware_crypto_native.py`)

Compiles the real `firmware/attendance_reader_PN532/crypto.hpp` against host
mbedTLS and verifies it produces the shared known-answer vectors. Needs a C++
compiler and the classic (pre-4.x) mbedTLS API.

```bash
# Debian/Ubuntu
sudo apt-get install -y libmbedtls-dev
# macOS (Homebrew's default mbedtls is 4.x and won't work here; use the v3 keg)
brew install mbedtls@3
```

The test discovers mbedTLS via `pkg-config` or a short list of prefixes
(including `/opt/homebrew/opt/mbedtls@3`). It generates `tests/native/_vectors_gen.h`
from `tests/fixtures/crypto_vectors.json` before compiling; that file is
gitignored. If mbedTLS is present but `crypto.hpp` fails to compile, that is a
**hard failure**, not a skip.

### Case geometry (`test_case_gen.py`)

```bash
.venv/bin/pip install -r case/requirements.txt
.venv/bin/pytest tests/test_case_gen.py
```

Regenerating all three STLs takes ~15 s on a cold matplotlib font cache (hence
the `slow` marker on the regeneration test).

---

## What each test file protects

### The core invariant

`software/attendance_crypto.py` (laptop) and the mbedTLS code in the firmware
must produce **byte-identical** tokens and ciphertext, or a roster built on the
laptop won't match cards on the device. Several test files exist only to guard
this.

| File | Goal |
|---|---|
| `test_attendance_crypto.py` | Unit tests for the crypto module: known-answer vectors (the same ones the firmware checks at boot), encrypt/decrypt round-trips over ASCII/Unicode/empty/39-char names, `token()` determinism and key-sensitivity, `load_or_create_key` (mode `0600`, idempotent, rejects bad keys), PKCS7 padding edge cases, and `decrypt_name` failure paths. |
| `test_crypto_contract.py` | The laptop/firmware contract, driven by `tests/fixtures/crypto_vectors.json`: (1) `attendance_crypto.py` reproduces every vector; (2) the firmware source still carries the literal token / ciphertext / plaintext for the vectors marked `firmware_selftest`. Editing crypto on one side without the other fails here. |
| `test_firmware_crypto_native.py` | Strongest guard: compiles the actual `crypto.hpp` against host mbedTLS and checks the same vectors plus `uidToKey`. Gated (`needs_mbedtls`). |

### Gradebook (`software/build_gradebook.py`)

The densest logic — name matching and Present/Late/Absent scoring on top of a
Canvas CSV rewrite. `main()` was split into `parse_args` / `build() -> Result` /
`render_report` / `write_output` so the logic is testable without scraping stdout.

| File | Goal |
|---|---|
| `test_gradebook_helpers.py` | Pure helpers: `norm_tokens` (order/case/punctuation independence), `fmt_points` (integer vs fraction formatting), `col_label` (stripping the trailing `(id)`), and the roster/alias loaders. |
| `test_gradebook_matching.py` | `match_row` against a tiny `CanvasIndex`: alias → SIS Login ID, exact normalized match, ambiguous (two students, same name), subset/superset "approx" match for middle initials, and the no-match case. |
| `test_gradebook_scoring.py` | `score_tap` tier boundaries (inclusive), tapped-before-start, `late_frac` points, earliest-tap-of-the-day wins, and multiple cards for one student keeping the best status. Registration-log crediting: a same-day registration with no tap is scored from its time (present or late), other dates are ignored, a real tap always wins, and a missing log is tolerated. |
| `test_gradebook_columns.py` | Resolving `--column` (exact label vs substring, zero/ambiguous → exit) and reading `Points Possible` (missing / non-numeric → default 1.0 with a warning), including an export with an extra `Manual Posting` row before `Points Possible`. |
| `test_gradebook_output.py` | Output integrity: only the target column changes, row count preserved, short rows padded; date filtering (`unsynced-*` counted not scored, wrong-date and malformed timestamps skipped); every report branch; `build()`'s `SystemExit` guards. |
| `test_gradebook_cli.py` | The thin CLI wrapper: `parse_args` defaults, `main(argv)` happy path, the Points-Possible warning print, missing-file exit, default output path. |

### Other laptop scripts

| File | Goal |
|---|---|
| `test_decode.py` | `software/decode_attendance.py`: `find_token_column`, `read_attendance` for both input formats (device `millis,token` and a sheet export with a `token` header) including the `time_col` selection edge, `token_to_name` decrypt/failure handling, and the extracted `decode()` / `main()`. |
| `test_register_core.py` | `software/register_cards.py` roster core (the tkinter GUI is out of scope): `normalize_key` (digit-strip, zero-pad, mod 2³² wrap), `valid_andrew_id` length bounds, `looks_like_card_scan` (an all-digit entry is a card tap, not an AndrewID), `load_roster`/`save_roster` round-trip (sorted, header, 32-char filter), `upsert` (added vs updated, returns previous value, count), and the `registration_log.csv` writer (sits beside the roster, header once, append-only). |
| `test_recover_sessions.py` | `software/recover_sessions.py`: `read_rows` drops truncated tokens, garbled (NUL-padded) timestamps and empty tokens, and skips the legacy 3-column format. `sessionize` splits on a millis reset or synced→unsynced, but not unsynced→synced, and a garbled row can't fracture a session. Also covers `describe_session` summaries, `parse_map` validation, and a `main()` run that checks the rewritten timestamps, the kept/dropped rows, and the per-date attendee report. |
| `test_sd_download.py` | `software/sd_download.py` parsers split out of the serial loop: `parse_dump` (between `<<<BEGIN>>>`/`<<<END>>>` markers), `parse_count`, and `find_port` matching rules. The serial I/O itself is `# pragma: no cover`. |
| `test_sd_upload.py` | `software/sd_upload.py` framing helpers split out of the serial loop: `checksum` (32-bit wrap), `build_header` (`<length> <checksum>`), `find_marker`, and `parse_result` (`<<<OK>>>`/`<<<ERR>>>` reply). The serial I/O itself is `# pragma: no cover`. |

### End-to-end

| File | Goal |
|---|---|
| `test_pipeline_e2e.py` | Golden test of the whole laptop chain: generate key → build `roster.csv` through the registration core → simulate a class of taps with `helpers.simulate_tap()` (the firmware oracle — it emits the exact `timestamp,token` rows the device logs) → `decode_attendance` → `build_gradebook` against `tests/fixtures/pipeline/Grades.csv`. The decoded report and the filled Canvas CSV are compared byte-for-byte against `tests/fixtures/pipeline/golden/`. Scenario covers present/late/absent, alias and approx matches, an unregistered card, an `unsynced-` row, a wrong-day row, and earliest-tap-wins. Also checks `uid_to_key` against the `DESIGN_NOTES` §2 example. |
| `test_case_gen.py` | `case/case_gen.py`: the committed STLs load and are watertight, and a fresh regeneration produces watertight meshes whose bounding boxes are within 1 mm of recorded baselines. Gated (`needs_trimesh`). |
| `test_smoke.py` | Phase-0 harness check: `software/` is importable, fixtures load. |

### Support files

- `tests/conftest.py` — shared fixtures (`kat_key`, `crypto_vectors`, `key_file`),
  the `--update-golden` option, and `assert_golden()`.
- `tests/helpers.py` — builders for Canvas / roster / attendance CSV fixtures, and
  the firmware oracles `simulate_tap()` and `uid_to_key()`.
- `tests/fixtures/crypto_vectors.json` — the single source of truth for the crypto
  known-answer vectors (shared by the Python and native tests).
- `tests/fixtures/pipeline/` — inputs (`Grades.csv`, `aliases.csv`) and committed
  `golden/` outputs for the end-to-end test.
- `tests/native/crypto_kat.cpp` — the native harness for `crypto.hpp`.

---

## Coverage

`pytest --cov` measures `software/` (see `.coveragerc`). `run_gui`, `__main__`
blocks, and serial I/O are excluded. The gate is **95%**; the suite currently
sits at ~98% (`decode_attendance`, `register_cards`, `sd_download`, `sd_upload`
at 100%; `build_gradebook` and `recover_sessions` at 98%; `attendance_crypto` at
96%). A new script without tests can push the total under the gate on its own,
so add its tests in the same change.

```bash
.venv/bin/pytest --cov --cov-report=term-missing   # per-line misses
.venv/bin/pytest --cov --cov-report=html && open htmlcov/index.html
```

---

## Updating golden files

`test_pipeline_e2e.py` compares against committed files in
`tests/fixtures/pipeline/golden/`. When you change output on purpose:

```bash
.venv/bin/pytest tests/test_pipeline_e2e.py --update-golden
git diff tests/fixtures/pipeline/golden/     # review every changed line
```

Only run this when the change is intended — the point of the golden files is that
an *unintended* output change fails CI.

---

## CI

`.github/workflows/tests.yml` runs on every push and PR:

- **pytest** — the full suite on Python 3.11–3.14, with `libmbedtls-dev`
  installed so the native crypto test runs. Coverage gate enforced.
- **case-geometry** — `test_case_gen.py` on one Python version with the geometry
  stack installed.
- **arduino-compile** — compiles the ESP32 sketch to catch syntax/API breakage.
  Non-blocking for now (`continue-on-error: true`); the board-package download is
  slow and flaky.

---

## Adding tests

- New tests go in `tests/test_*.py`; functions are `test_*`.
- Reuse `tests/helpers.py` for CSV fixtures and `tests/conftest.py` for the KAT
  key / vectors. Build temp files under `tmp_path`.
- If you touch the crypto on either side, add or update a row in
  `tests/fixtures/crypto_vectors.json` and keep the firmware self-test literals in
  step (`test_crypto_contract.py` will tell you if they drift).
- Keep `software/` coverage at or above the gate; exclude genuinely
  hardware-only code with `# pragma: no cover` and a short reason.

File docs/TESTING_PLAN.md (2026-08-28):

# Testing Plan

How we get this project under automated test, and why in this order. Companion to
`docs/TESTING_GUIDE.md` (which is a manual, hardware-in-the-loop walkthrough) — this
doc is the *automated* strategy: what runs in CI on every push, with no device
plugged in.

The guiding constraint: **the laptop Python and the ESP32 firmware must produce
byte-identical tokens and ciphertext** (`CONTRIBUTING.md`, `DESIGN_NOTES.md` §6).
Most of the test effort exists to protect that and the gradebook logic on top of it.

---

## 0. Status — Phases 0–6 built

All phases below are implemented. `pytest` from the repo root runs green
(~190 tests, <2 s) with **99% line coverage** of `software/` and a 95% gate in
`.coveragerc`. Per-module: `build_gradebook`, `decode_attendance`,
`register_cards`, `sd_download` at 100%; `attendance_crypto` at 96% (the
`os.chmod` fallback). CI (`.github/workflows/tests.yml`) runs the suite on Python
3.11–3.14 plus a `case-geometry` job and a non-blocking `arduino-compile` job.

Notes on what shipped vs. the plan below:

- Deps live in `software/requirements.txt`, `requirements-dev.txt`, and
  `case/requirements.txt`; local dev uses a repo-root `.venv/` (PEP 668).
- `decode_attendance`'s extracted core is `decode()` (the plan said `run()`).
- The native firmware-crypto test (`test_firmware_crypto_native.py`) compiles the
  real `firmware/attendance_reader_PN532/crypto.hpp` against host mbedTLS. It
  canary-probes for the classic pre-4.x mbedTLS API and skips on mbedTLS ≥ 4
  (Homebrew's default) as well as when no compiler/mbedTLS is present; CI installs
  `libmbedtls-dev` so it runs there.
- `test_case_gen.py` also checks the committed STLs load and are watertight, not
  just a fresh regeneration.

---

## 1. Original starting point

There were **no automated tests**, no `pytest` config, and no CI. `cryptography`,
`pytest`, and `pyserial` were not installed. The `.example` fixtures
(`Grades.csv.example`, `aliases.csv.example`, `wifi_config.h.example`) were the
only thing resembling test data, exercised only by hand.

---

## 2. What we're testing, and how testable it is

| Component | Nature | Testability | Priority |
|---|---|---|---|
| `software/attendance_crypto.py` | Pure functions (HMAC token, AES name enc/dec, key mgmt) | Trivial — pure in/out | **Critical** |
| `software/build_gradebook.py` | Name matching + Present/Late/Absent scoring + Canvas CSV rewrite | Helpers pure; `main()` is a ~160-line monolith | **Highest** |
| `software/decode_attendance.py` | Token log → names report; two input formats | Mostly pure, thin `main()` | High |
| `software/register_cards.py` | Roster core (`normalize_key`, `load/save/upsert`) + tkinter GUI | Core is already marked "testable"; GUI is not | High (core only) |
| `software/sd_download.py` | Serial download; `<<<BEGIN>>>`/`<<<END>>>` marker parsing | Parsing tangled with `serial` I/O | Medium |
| `software/reader_test.py` | Interactive diagnostic REPL | Not worth testing | Skip |
| `firmware/attendance_reader_PN532/…ino` | Arduino/ESP32 C++; mbedTLS crypto + UI + SD + NFC | No host build today | Medium (protect crypto only) |
| `case/case_gen.py` | trimesh / manifold3d / shapely / matplotlib geometry | Heavy deps; slow | Low (smoke only) |

---

## 3. Test taxonomy

1. **Unit** — crypto known-answer vectors and properties; name normalization; the
   matching algorithm; the scoring tiers; CSV/format parsers.
2. **Contract** — the Python crypto reproduces the exact vectors hard-coded in the
   firmware's `cryptoSelfTest()`, so drift on either side fails CI.
3. **Golden / end-to-end** — the whole laptop pipeline (key → roster → simulated
   taps → decode → gradebook) against committed fixtures with committed expected
   output.
4. **CLI** — argument parsing, exit codes, and error messages (missing files, bad
   `--date`, ambiguous `--column`).
5. **Gated / optional** — native firmware crypto binary, `arduino-cli` compile,
   `case_gen.py` smoke + dimensional regression. Skipped automatically when their
   toolchain isn't present.

---

## 4. Infrastructure

- `software/requirements.txt` — `cryptography`, `pyserial` (runtime deps, currently
  only named in docstrings).
- `requirements-dev.txt` — `pytest`, `pytest-cov`.
- `pyproject.toml` → `[tool.pytest.ini_options]`:
  - `pythonpath = ["software"]` so `import attendance_crypto as ac` resolves without
    packaging the scripts.
  - `testpaths = ["tests"]`.
  - markers: `hardware`, `slow`, `needs_trimesh`, `needs_mbedtls`.
- `tests/` at the repo root; `tests/fixtures/` holds:
  - `crypto_vectors.json` — the single source of truth for KAT vectors (shared by
    the Python tests and the firmware contract test).
  - `Grades.csv`, `roster.csv`, `attendance.csv` — small synthetic inputs.
  - `golden/` — expected `*_filled.csv` and decoded reports.
- `.coveragerc` — omit `run_gui`, all `if __name__ == "__main__"` blocks, and the
  `serial`-only code in `sd_download.py`.
- `.github/workflows/tests.yml` — Python 3.11–3.14 matrix; install both requirements
  files; `pytest --cov`; print coverage. Separate **optional** jobs (allowed to
  fail / manually triggered) for `arduino-cli compile` and the case smoke test.
- `CONTRIBUTING.md` — replace "Run the relevant Python script against the `.example`
  fixtures" with `pip install -r requirements-dev.txt && pytest`.

---

## 5. Refactoring for testability

Small, behaviour-preserving changes done alongside the tests that cover them.

### 5.1 `build_gradebook.py` — split `main()`

`main()` currently parses args, reads four files, runs the whole matching/scoring
algorithm in nested closures, prints a report, and writes a file. Split into:

- `parse_args(argv) -> Namespace`
- `build(canvas_path, attendance_path, roster, aliases, session) -> Result`
  where `Result` is a dataclass: `rows_out`, `present/late/absent`, `unmatched`,
  `ambiguous`, `unregistered`, `unsynced`, `target_header`.
- `render_report(result) -> str`
- `write_output(path, rows)`

Lift `match_row` to module scope (take an explicit `CanvasIndex` — `by_login`,
`by_norm`, `student_rows`, `rows`, `c_student` — instead of closing over `main`'s
locals). Tests then assert on `Result` fields instead of scraping stdout.

### 5.2 `register_cards.py` — lift the state machine out of tkinter

Extract from `on_return`:

- `classify_scan(raw) -> ("bad", None) | ("ok", card_id)`
- `resolve_tap(roster, K, card_id) -> ("already", name) | ("new", token)`
- `prepare_save(raw_name) -> str | None`  (trim, cap at 39 chars, reject empty)

`on_return` becomes glue calling these. The `"0000000000"` sentinel check moves
into `classify_scan`.

### 5.3 `decode_attendance.py` — return instead of only printing

`main()` is already thin; add `run(attendance, roster, key, out) -> (scanned,
unknown, registered)` and have `main()` print from that.

### 5.4 `sd_download.py` — separate parsing from the port

Extract `parse_dump(lines) -> list[str]` and `parse_count(lines) -> int | None`
from the serial loops. `main()` keeps all `serial` calls and feeds
`ser`-derived line iterators to the pure parsers.

### 5.5 firmware — extract an Arduino-free crypto header

Move `uidToKey`, `toHex`, `hexToBytes`, `deriveKeysFrom`, `computeToken`,
`decryptNameWith` into `firmware/attendance_reader_PN532/crypto.hpp` depending
only on `mbedtls/*` (no `Arduino.h`, no `String`). The `.ino` `#include`s it; a
native test binary (5.x, Phase 5) links the same header.

### 5.6 `attendance_crypto.py` — minor

Use a `with` block in `load_or_create_key` (currently leaks the read handle).
Move the `__main__` body into `_cli()`. No API change.

---

## 6. Phases

### Phase 0 — Infrastructure
Everything in §4. CI goes green with a single trivial test. No production code
touched.

### Phase 1 — Crypto unit + contract tests
`tests/test_attendance_crypto.py`:

- **KAT, must match the firmware** (`cryptoSelfTest()` in the `.ino`): key
  `00,01,…,1f`; `token(K, "0984257796") == "f989b34da0e80527fc371aabb3ac7402"`;
  `decrypt_name(K, "000102…0e0f" + "bc2085cdcb6691b378e61607857a54e4") ==
  "Michael Hilton"`.
- Roundtrip property: `decrypt_name(K, encrypt_name(K, s)) == s` for ASCII,
  Unicode, `""`, and a 39-char name.
- `token`: deterministic; distinct ids → distinct tokens; changes with the key;
  always 32 lowercase hex.
- `subkeys`: `kmac != kenc`; stable for a given `K`.
- `load_or_create_key`: creates a 64-hex file at mode `0600`; **idempotent**
  (second call returns the same bytes, file not rewritten); rejects a 32-hex file;
  tolerates a trailing newline.
- PKCS7: a full 16-byte pad is added when `len(plaintext) % 16 == 0`; `_unpkcs7`
  rejects `pad == 0`, `pad > 16`, and a corrupted pad trailer.
- `decrypt_name` failure paths: odd-length hex, ciphertext shorter than one block,
  wrong key → `ValueError("bad padding")`.
- `firmware_key_snippet`: 32 `0x??` bytes, contains `#pragma once` and
  `SECRET_KEY[32]`.

`tests/test_crypto_contract.py`:

- Every row of `tests/fixtures/crypto_vectors.json` reproduced by
  `attendance_crypto`.
- Parse the literals out of `attendance_reader_PN532.ino` (`cryptoSelfTest`) and
  assert they equal the fixture. Drift on either side fails.

### Phase 2 — Pure helpers (no refactor required)
- `tests/test_gradebook_helpers.py` — `norm_tokens` (order independence, punctuation
  → space, dedupe), `fmt_points` (`1.0→"1"`, `0.5→"0.5"`, near-integer tolerance,
  trailing-zero strip), `col_label` (`"Jan 20 Activity (995978)" → "jan 20
  activity"`), `load_token_names` / `load_aliases` (header rows, blanks,
  decrypt-fail sentinel, missing file).
- `tests/test_decode.py` — `find_token_column`; `read_attendance` for both the
  sheet-export format (has a `token` header) and the device format (`millis,token`),
  including the `time_col` selection branch, the 32-char token filter, short rows,
  and an empty file.
- `tests/test_register_core.py` — `normalize_key` (`"0984257796"` → itself; letters
  / spaces / newlines stripped; `""` → `""`; value ≥ 2³² wraps; leading zeros
  preserved); `load_roster`/`save_roster` roundtrip (sorted by token, header
  written, 32-char filter, missing enc column → `""`); `upsert` (added vs updated,
  returns previous enc, count correct, persisted to disk).

### Phase 3 — Refactor + high-value gradebook tests
Do §5.1–5.4, each landing with its tests:

- `tests/test_gradebook_matching.py` — table over `match_row`: alias → SIS Login
  ID; exact normalized unique; exact but ambiguous (two students same normalized
  name) → `None, "ambiguous"`; subset match (middle initial); superset match;
  nothing → `None, "none"`.
- `tests/test_gradebook_scoring.py` — boundaries at `late_after` and `close`
  (inclusive); late value is `round(full * late_frac, 4)`; earliest tap per token
  wins; two cards → one student keeps the best status by `present>late>absent`
  rank; tap after `close` → absent 0; never-tapped student → absent 0.
- `tests/test_gradebook_columns.py` — exact `col_label` match preferred over
  substring; zero matches → `SystemExit`; multiple → `SystemExit` "ambiguous";
  `Points Possible` missing / non-numeric → default `1.0` with a warning line.
- `tests/test_gradebook_output.py` — every student row padded to at least
  `c_target + 1` cells; **only** the target column changes; total row count and
  identity columns preserved (re-imports cleanly); `unsynced-*` rows counted, not
  scored; wrong-date and malformed-timestamp rows skipped.
- `tests/test_sd_download.py` — `parse_dump` (marker pair, no markers, `<<<BEGIN`
  with no `<<<END`); `parse_count`; `find_port` matching rules.

### Phase 4 — Golden end-to-end
`tests/test_pipeline_e2e.py` with a `simulate_tap(K, card_id, when)` helper that
reproduces the firmware's `uidToKey` + `computeToken` + `"%Y-%m-%d %H:%M:%S,token"`
log line (this helper is also the firmware oracle). Flow:

1. `load_or_create_key` in a tmp dir.
2. `register_cards` core builds `roster.csv` for a few students.
3. Simulate a class: on-time taps, a late tap, an after-close tap, an unregistered
   card, an `unsynced-` row.
4. `decode_attendance.run(...)` → assert the report.
5. `build_gradebook.build(...)` against `tests/fixtures/Grades.csv` (shaped like
   `Grades.csv.example`) → assert the filled CSV **byte-for-byte** against
   `tests/fixtures/golden/Grades_filled.csv` and every `Result` count.

A `--update-golden` pytest flag (in `conftest.py`) regenerates the golden files.

### Phase 5 — Firmware crypto (gated)
- **Contract test** already landed in Phase 1 — keep it as the always-on guard.
- **Native KAT binary** (`needs_mbedtls`): after §5.5, a `tests/native/` `g++`
  target links `crypto.hpp` against system `libmbedcrypto` and asserts the same
  `crypto_vectors.json`. `pytest` shells out to build+run it; skips cleanly if no
  compiler or mbedTLS.
- **`arduino-cli compile`** — optional CI job, `--fqbn esp32:esp32:esp32`, catches
  syntax/API breakage in the full sketch. Slow (board package download); not on the
  critical path.

### Phase 6 — Case generator (gated, low priority)
`tests/test_case_gen.py`, marked `needs_trimesh`: run `case_gen.py` in a tmp cwd,
assert the three STLs are written and `trimesh.load(...).is_watertight` for each,
and that each mesh's bounding box is within tolerance of a recorded baseline.

---

## 7. Coverage target

~90% line coverage on `attendance_crypto.py`, `build_gradebook.py`,
`decode_attendance.py`, and the `register_cards.py` core. `run_gui`, `__main__`
blocks, and `serial` I/O are excluded via `.coveragerc`, not counted against the
target. CI fails under the threshold once Phase 3 lands.

---

## 8. Latent issues these tests will pin

Not fixed as part of test setup — but each gets a test documenting current
behaviour so a later fix is a deliberate, visible change:

- **`build_gradebook.py` — student-row detection by `"@" in SIS Login ID`**
  (`build_gradebook.py:143`, also in `ROADMAP.md`). An export with a bare Andrew ID
  there yields "0 enrolled" and marks everyone absent, silently.
- **`decode_attendance.py:62`** — a single-column sheet export makes
  `time_col == tok_col`, so the report's time field is the token.
- **`attendance_crypto.py:27`** — `open(path)` read handle is never closed
  (fixed in §5.6).

---

## 9. Sequencing

Phases 0–2 need **no** production changes and cover the crypto contract — do them
first. Phase 3 is where the refactor and the real gradebook payoff land. Phases
4–6 build on that. Each phase leaves CI green.

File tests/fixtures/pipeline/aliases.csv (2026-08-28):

typed_name | sis_login_id
Ick Park | eun.park@example.edu

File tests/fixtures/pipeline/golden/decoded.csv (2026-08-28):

raw_time | name
2026-08-27 09:58:00 | Alice Chen
2026-08-27 10:07:30 | Bob Diaz
2026-08-27 10:18:00 | Cara Osei
2026-08-27 10:45:00 | David Nguyen
2026-08-27 10:03:00 | Ick Park
2026-08-27 10:05:00 | Ghost Student
2026-08-27 10:06:00 | UNKNOWN deadbeef
unsynced-12345 | Bob Diaz
2026-08-26 10:00:00 | Alice Chen
2026-08-27 10:02:00 | Alice Chen

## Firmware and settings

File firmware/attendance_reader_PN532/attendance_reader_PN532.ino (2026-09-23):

/*
 * Classroom Attendance Reader — 3.5" CYD + PN532 (fast/responsive build)
 * -----------------------------------------------------------------------------
 * Board : ESP32-3248S035C  (Sunton CYD, 3.5" ST7796 screen, ESP32-WROOM-32)
 * Reader: PN532 NFC (13.56 MHz) over I2C — reads the card UID
 * Sound : small 8ohm speaker on the "SPEAK" connector (GPIO26) — optional
 *
 * Libraries (Library Manager): "TFT_eSPI" (Bodmer), "Adafruit PN532" (+ Adafruit BusIO)
 * Wiring: PN532 VCC->3V3, GND->GND, SDA->IO21, SCL->IO22 (CN1); DIP switches = I2C.
 * PRIVACY: card numbers are NEVER stored. roster.csv holds (token,enc_name) where
 *   token   = HMAC-SHA256(secret, id)[:16]   (one-way; can't recover the card number)
 *   enc_name= AES-256-CBC(secret, name)      (device decrypts to show the name)
 *   attendance.csv = (timestamp,token) — stored locally only; WiFi is used just for NTP time.
 * Build roster.csv with register_cards.py; decode attendance with decode_attendance.py.
 * TIP: bump SPI_FREQUENCY to 40000000 in TFT_eSPI User_Setup.h for faster draws.
 * -----------------------------------------------------------------------------
 */

#include <WiFi.h>
#include <time.h>
#include <SPI.h>
#include <SD.h>
#include <Wire.h>
#include <Adafruit_PN532.h>
#include <TFT_eSPI.h>
#include "mbedtls/md.h"
#include "mbedtls/aes.h"
#include "crypto.hpp"   // uidToKey / deriveKeysFrom / computeToken / decryptNameWith
                        // (shared byte-for-byte with software/attendance_crypto.py)

// ------------------------------ USER SETTINGS -------------------------------
// WiFi credentials live in wifi_config.h (kept out of version control via
// .gitignore) so real credentials never sit in the tracked sketch. If that file
// is missing the sketch still compiles with the placeholders below — put your
// network in wifi_config.h, not here.
#if __has_include("wifi_config.h")
  #include "wifi_config.h"
#endif
#ifndef WIFI_SSID
  #define WIFI_SSID "YOUR_WIFI_SSID"
#endif
#ifndef WIFI_PASS
  #define WIFI_PASS "YOUR_WIFI_PASSWORD"
#endif
// WiFi is used ONLY to set the clock over NTP (no cloud upload). TZ = US Eastern (Pittsburgh).
const char* NTP1    = "pool.ntp.org";
const char* NTP2    = "time.nist.gov";
const char* TZ_INFO = "EST5EDT,M3.2.0,M11.1.0";

// --- SECRET KEY lives in secret_key.h (kept out of version control via
// .gitignore, same pattern as wifi_config.h above), never in this tracked file.
// Run `python3 attendance_crypto.py` from software/ — it writes secret_key.h
// directly into this sketch folder. If that file is missing, the sketch still
// compiles using the placeholder key below, but tokens/names won't match any
// real roster until you generate and drop in the real one. ---
#if __has_include("secret_key.h")
  #include "secret_key.h"
#else
  static const uint8_t SECRET_KEY[32] = {
    0x00, 0x01, 0x02, 0x03, 0x04, 0x05, 0x06, 0x07, 0x08, 0x09, 0x0a, 0x0b, 0x0c, 0x0d, 0x0e, 0x0f,
    0x10, 0x11, 0x12, 0x13, 0x14, 0x15, 0x16, 0x17, 0x18, 0x19, 0x1a, 0x1b, 0x1c, 0x1d, 0x1e, 0x1f
  };  // <-- placeholder only. Never used for a real roster.
#endif
uint8_t KMAC[32], KENC[32];

#define PN532_IRQ   255
#define PN532_RESET 255
#define SD_SCK  18
#define SD_MISO 19
#define SD_MOSI 23
#define SD_CS    5
#define SPEAKER_PIN 26

const unsigned long COOLDOWN_MS = 3000;   // ignore same card again within 3 s
const unsigned long RESULT_MS   = 1500;   // how long the name stays on screen
#define MAX_STUDENTS 300
// ----------------------------------------------------------------------------

TFT_eSPI        tft = TFT_eSPI();
SPIClass        sdSPI(VSPI);
Adafruit_PN532  nfc(PN532_IRQ, PN532_RESET);

struct Entry { char token[33]; char enc[130]; };   // HMAC token + AES-encrypted name (hex)
Entry roster[MAX_STUDENTS];
int   rCount = 0;

char          lastUid[15] = {0};
unsigned long lastTagTime = 0;
unsigned long resultUntil = 0;
bool          showingResult = false;
bool          sdOK = false, nfcOK = false;


// ------------------------------- helpers ------------------------------------
int cmpEntry(const void* a, const void* b) {
  return strcmp(((const Entry*)a)->token, ((const Entry*)b)->token);
}

// ------------------------------- crypto -------------------------------------
// The primitives (uidToKey / sha256 / hmac256 / toHex / hexToBytes /
// deriveKeysFrom / computeToken / decryptNameWith) live in crypto.hpp so the
// host test suite can link and check them. The two thin wrappers below bind
// them to this sketch's globals (SECRET_KEY, KMAC, KENC).
void deriveKeys() { deriveKeysFrom(SECRET_KEY, KMAC, KENC); }

bool decryptName(const char* encHex, char* out, size_t outsz) {
  return decryptNameWith(KENC, encHex, out, outsz);
}
// Prove mbedTLS matches the laptop tools using a fixed test vector (key = 00..1f).
void cryptoSelfTest() {
  uint8_t TK[32]; for (int i = 0; i < 32; i++) TK[i] = i;
  uint8_t km[32], ke[32]; deriveKeysFrom(TK, km, ke);
  uint8_t mac[32]; hmac256(km, 32, (const uint8_t*)"0984257796", 10, mac);
  char hx[33]; toHex(mac, 16, hx);
  bool tOK = (strcmp(hx, "f989b34da0e80527fc371aabb3ac7402") == 0);
  char nm[40];
  bool aOK = decryptNameWith(ke,
    "000102030405060708090a0b0c0d0e0fbc2085cdcb6691b378e61607857a54e4", nm, sizeof(nm))
    && strcmp(nm, "Michael Hilton") == 0;
  Serial.printf("crypto self-test: HMAC %s, AES %s\n", tOK ? "OK" : "FAIL", aOK ? "OK" : "FAIL");
}

// Redraw ONLY the center text band (much faster than fillScreen).
void drawStatus(const char* big, const char* small, uint16_t color) {
  int cy = tft.height() / 2;
  tft.fillRect(0, cy - 70, tft.width(), 140, TFT_BLACK);
  tft.setTextDatum(MC_DATUM);
  tft.setTextColor(color, TFT_BLACK);
  tft.setTextSize(3);
  tft.drawString(big, tft.width() / 2, cy - 20);
  tft.setTextColor(TFT_WHITE, TFT_BLACK);
  tft.setTextSize(2);
  tft.drawString(small, tft.width() / 2, cy + 26);
}

void beepKnown()   { tone(SPEAKER_PIN, 2000, 120); }   // short high ding
void beepUnknown() { tone(SPEAKER_PIN, 350, 250);  }   // low buzz

// --------------------------- top status bar --------------------------------
// A 26 px band across the top: NTP clock on the left, WiFi state on the right.
// Sits clear of drawStatus()'s center band (height/2 +/- 70), so the two never
// fight. Each half is only repainted when its text actually changes, so calling
// this once a second from loop() costs almost nothing and doesn't flicker.
// No battery indicator yet -- see docs/DESIGN_NOTES.md section 5 for why.
void drawTopBar(bool force = false) {
  const int   H   = 26;
  const int   mid = tft.width() / 2;
  static char lastTs[24] = {0};
  static int  lastWifi   = -1;

  struct tm t;
  char ts[24];
  uint16_t tcol;
  if (getLocalTime(&t, 20) && (t.tm_year + 1900) >= 2024) {
    strftime(ts, sizeof(ts), "%Y-%m-%d %H:%M:%S", &t);
    tcol = TFT_WHITE;
  } else {
    strcpy(ts, "clock not set");                 // no RTC: blank until WiFi+NTP
    tcol = TFT_ORANGE;
  }

  tft.setTextSize(2);

  if (force || strcmp(ts, lastTs) != 0) {        // left half: clock
    tft.fillRect(0, 0, mid, H, TFT_NAVY);
    tft.setTextDatum(ML_DATUM);
    tft.setTextColor(tcol, TFT_NAVY);
    tft.drawString(ts, 4, H / 2);
    strcpy(lastTs, ts);
  }

  int up = (WiFi.status() == WL_CONNECTED) ? 1 : 0;
  if (force || up != lastWifi) {                 // right half: WiFi state
    tft.fillRect(mid, 0, tft.width() - mid, H, TFT_NAVY);
    tft.setTextDatum(MR_DATUM);
    tft.setTextColor(up ? TFT_GREEN : TFT_RED, TFT_NAVY);
    tft.drawString(up ? "WiFi" : "no WiFi", tft.width() - 4, H / 2);
    lastWifi = up;
  }
}

// ---------------------- WiFi serial diagnostics (DEBUG) -------------------
// Temporary bring-up aid: prints to USB serial why WiFi is / isn't connecting.
// Watch with:  arduino-cli monitor -p <port> -c baudrate=115200
// Remove this block (and its two call sites) once WiFi is confirmed working.
static const char* wlStatusStr(int s) {
  switch (s) {
    case WL_IDLE_STATUS:     return "IDLE";
    case WL_NO_SSID_AVAIL:   return "NO_SSID_AVAIL (network not seen)";
    case WL_SCAN_COMPLETED:  return "SCAN_COMPLETED";
    case WL_CONNECTED:       return "CONNECTED";
    case WL_CONNECT_FAILED:  return "CONNECT_FAILED (wrong password?)";
    case WL_CONNECTION_LOST:  return "CONNECTION_LOST";
    case WL_DISCONNECTED:    return "DISCONNECTED";
    default:                 return "UNKNOWN";
  }
}

// One synchronous scan before WiFi.begin(): shows every 2.4 GHz AP the ESP32
// can actually see, and whether our target SSID is among them.
void wifiScanReport() {
  Serial.printf("[wifi] target SSID=\"%s\"  pass length=%d\n",
                WIFI_SSID, (int)strlen(WIFI_PASS));
  Serial.println("[wifi] scanning 2.4 GHz...");
  int n = WiFi.scanNetworks();
  if (n <= 0) {
    Serial.println("[wifi] scan saw NO networks (2.4 GHz radio/antenna problem?)");
    return;
  }
  bool sawTarget = false;
  for (int i = 0; i < n; i++) {
    bool match = (WiFi.SSID(i) == WIFI_SSID);
    sawTarget |= match;
    Serial.printf("[wifi]  %2d) %-32s  RSSI %4d  ch %2d  %s%s\n",
                  i + 1, WiFi.SSID(i).c_str(), WiFi.RSSI(i), WiFi.channel(i),
                  (WiFi.encryptionType(i) == WIFI_AUTH_OPEN) ? "open" : "secured",
                  match ? "   <-- MATCH" : "");
  }
  if (!sawTarget)
    Serial.printf("[wifi] *** \"%s\" NOT in scan. Check the exact iPhone name and "
                  "turn ON Personal Hotspot > Maximize Compatibility. ***\n", WIFI_SSID);
  WiFi.scanDelete();
}

// Call every loop(): rate-limited progress report until WiFi + NTP are up.
void wifiDiagTick() {
  static unsigned long last = 0;
  static bool wasConnected = false, ntpDone = false;
  if (millis() - last < 2000) return;
  last = millis();

  int st = WiFi.status();
  if (st != WL_CONNECTED) {
    wasConnected = false;
    Serial.printf("[wifi] status=%s\n", wlStatusStr(st));
    return;
  }
  if (!wasConnected) {
    Serial.printf("[wifi] CONNECTED  ip=%s  gw=%s  rssi=%d dBm\n",
                  WiFi.localIP().toString().c_str(),
                  WiFi.gatewayIP().toString().c_str(), WiFi.RSSI());
    wasConnected = true;
  }
  if (!ntpDone) {
    struct tm t;
    if (getLocalTime(&t, 0) && (t.tm_year + 1900) >= 2024) {
      char ts[24]; strftime(ts, sizeof(ts), "%Y-%m-%d %H:%M:%S", &t);
      Serial.printf("[ntp]  clock set: %s\n", ts);
      ntpDone = true;
    } else {
      Serial.println("[ntp]  connected, waiting for NTP...");
    }
  }
}

// ------------------------------- roster -------------------------------------
void loadRoster() {
  rCount = 0;
  if (!sdOK) return;
  File f = SD.open("/roster.csv");
  if (!f) return;
  while (f.available() && rCount < MAX_STUDENTS) {
    String line = f.readStringUntil('\n');
    line.trim();
    if (line.length() == 0) continue;
    int c = line.indexOf(',');
    if (c < 0) continue;
    String tk = line.substring(0, c);  tk.trim();
    String en = line.substring(c + 1); en.trim();
    if (tk.length() != 32) continue;                            // skip header / bad rows (token = 32 hex)
    strncpy(roster[rCount].token, tk.c_str(), 32); roster[rCount].token[32] = 0;
    strncpy(roster[rCount].enc,   en.c_str(), sizeof(roster[rCount].enc) - 1);
    roster[rCount].enc[sizeof(roster[rCount].enc) - 1] = 0;
    rCount++;
  }
  f.close();
  qsort(roster, rCount, sizeof(Entry), cmpEntry);               // sort for bsearch
}

const Entry* lookupToken(const char* token) {
  Entry key; strncpy(key.token, token, 32); key.token[32] = 0;
  return (const Entry*)bsearch(&key, roster, rCount, sizeof(Entry), cmpEntry);
}

// Local timestamp "YYYY-MM-DD HH:MM:SS" from NTP; "unsynced-<millis>" until the clock is set.
void getTimestamp(char* out, size_t n) {
  struct tm t;
  if (getLocalTime(&t, 50) && (t.tm_year + 1900) >= 2024) {
    strftime(out, n, "%Y-%m-%d %H:%M:%S", &t);
  } else {
    snprintf(out, n, "unsynced-%lu", (unsigned long)millis());
  }
}

void logToSD(const char* token) {                               // attendance stores timestamp + token
  if (!sdOK) return;
  char ts[32]; getTimestamp(ts, sizeof(ts));
  File f = SD.open("/attendance.csv", FILE_APPEND);
  if (f) { f.printf("%s,%s\n", ts, token); f.close(); }
}

// ---------- serial commands over USB (dump / roster / upload / count / help) ----------
// Print a file wrapped in markers the Python downloader looks for.
void dumpFile(const char* path, const char* label) {
  Serial.printf("<<<BEGIN %s>>>\n", label);
  if (!sdOK) { Serial.println("(no SD card)"); }
  else {
    File f = SD.open(path);
    if (!f) Serial.println("(file not found)");
    else { while (f.available()) Serial.write(f.read()); f.close(); }
  }
  Serial.printf("\n<<<END %s>>>\n", label);
}

// Receive a new roster.csv over USB and replace the one on the SD card.
// Protocol:  host sends "upload\n"  ->  device prints "<<<READY>>>"
//            host sends "<length> <checksum>\n"  then <length> raw bytes
//            (checksum = sum of every byte, wrapped to 32 bits)
//            device -> "<<<OK roster.csv N bytes, M entries>>>"  on success
//                      "<<<ERR ...>>>"                            otherwise
// The file is streamed to /roster.new, verified (size + checksum), then renamed
// over /roster.csv so a dropped connection never corrupts the live roster.
void recvRoster() {
  if (!sdOK) { Serial.println("<<<ERR no SD card>>>"); return; }
  Serial.println("<<<READY>>>");

  // ---- header line: "<length> <checksum>" (30 s to arrive) ----
  char hdr[48]; int hn = 0; unsigned long t0 = millis();
  while (millis() - t0 < 30000) {
    int c = Serial.read();
    if (c < 0) continue;
    if (c == '\r') continue;
    if (c == '\n') break;
    if (hn < (int)sizeof(hdr) - 1) hdr[hn++] = (char)c;
  }
  hdr[hn] = 0;
  unsigned long want = 0, wantSum = 0;
  if (sscanf(hdr, "%lu %lu", &want, &wantSum) != 2 || want == 0 || want > 200000UL) {
    Serial.printf("<<<ERR bad header '%s'>>>\n", hdr);
    return;
  }

  drawStatus("Updating", "roster...", TFT_YELLOW);

  // ---- stream the bytes into a temp file ----
  SD.remove("/roster.new");
  File f = SD.open("/roster.new", FILE_WRITE);
  if (!f) { Serial.println("<<<ERR cannot open /roster.new>>>"); return; }

  uint8_t buf[256];
  unsigned long got = 0, sum = 0;
  t0 = millis();
  while (got < want && millis() - t0 < 15000) {
    size_t chunk = want - got;
    if (chunk > sizeof(buf)) chunk = sizeof(buf);
    int nread = Serial.readBytes(buf, chunk);          // honours the 1 s stream timeout
    if (nread <= 0) continue;
    f.write(buf, nread);
    for (int i = 0; i < nread; i++) sum += buf[i];
    sum &= 0xFFFFFFFFUL;
    got += nread;
    t0 = millis();
  }
  f.close();

  if (got != want || sum != wantSum) {
    SD.remove("/roster.new");
    Serial.printf("<<<ERR got %lu/%lu bytes, sum %lu/%lu>>>\n", got, want, sum, wantSum);
    drawStatus("Update", "FAILED", TFT_RED);
    return;
  }

  SD.remove("/roster.csv");
  if (!SD.rename("/roster.new", "/roster.csv")) {
    Serial.println("<<<ERR rename failed>>>");
    drawStatus("Update", "FAILED", TFT_RED);
    return;
  }

  loadRoster();
  Serial.printf("<<<OK roster.csv %lu bytes, %d entries>>>\n", want, rCount);
  char note[40]; snprintf(note, sizeof(note), "%d in roster", rCount);
  drawStatus("Updated", note, TFT_GREEN);
  resultUntil = millis() + RESULT_MS;
  showingResult = true;
}

void handleSerial() {
  static char cmd[16]; static int n = 0;
  while (Serial.available()) {
    char c = Serial.read();
    if (c == '\n' || c == '\r') {
      if (n == 0) continue;
      cmd[n] = 0; n = 0;
      if      (!strcasecmp(cmd, "dump"))   dumpFile("/attendance.csv", "attendance.csv");
      else if (!strcasecmp(cmd, "roster")) dumpFile("/roster.csv", "roster.csv");
      else if (!strcasecmp(cmd, "upload")) recvRoster();
      else if (!strcasecmp(cmd, "count")) {
        int rows = -1;
        if (sdOK) { File f = SD.open("/attendance.csv"); if (f) { rows = 0; while (f.available()) if (f.read() == '\n') rows++; f.close(); } }
        Serial.printf("attendance rows: %d\n", rows > 0 ? rows - 1 : 0);   // minus header
      }
      else if (!strcasecmp(cmd, "help") || !strcmp(cmd, "?"))
        Serial.println("Commands: dump | roster | upload | count | help");
      else Serial.printf("? unknown '%s' (try 'help')\n", cmd);
    } else if (n < 15) cmd[n++] = c;
  }
}

// --------------------------------- setup ------------------------------------
void setup() {
  Serial.begin(115200);
  deriveKeys();          // derive KMAC/KENC from SECRET_KEY
  cryptoSelfTest();      // prints HMAC/AES OK|FAIL — must be OK for the roster to match

  tft.init();
  tft.setRotation(1);   // board mounted rotated 180 deg (cable exits bottom-left)
  tft.fillScreen(TFT_BLACK);
  drawStatus("Booting", "please wait", TFT_WHITE);

  sdSPI.begin(SD_SCK, SD_MISO, SD_MOSI, SD_CS);
  sdOK = SD.begin(SD_CS, sdSPI);
  if (sdOK && !SD.exists("/attendance.csv")) {
    File f = SD.open("/attendance.csv", FILE_WRITE);
    if (f) { f.println("timestamp,token"); f.close(); }
  }
  loadRoster();

  Wire.begin();
  delay(50);
  nfc.begin();
  uint32_t ver = 0;                          // retry: PN532 can be slow/mid-state after a reset
  for (int i = 0; i < 12 && ver == 0; i++) { ver = nfc.getFirmwareVersion(); if (!ver) delay(100); }
  nfcOK = (ver != 0);
  if (nfcOK) {
    nfc.SAMConfig();
  }

  WiFi.mode(WIFI_STA);
  WiFi.setAutoReconnect(true);
  wifiScanReport();                          // DEBUG: list visible APs, flag if target missing
  WiFi.begin(WIFI_SSID, WIFI_PASS);          // connects in the background (for NTP only)
  configTzTime(TZ_INFO, NTP1, NTP2);         // set the clock over NTP once WiFi is up

  char note[40];
  if (!nfcOK)       strcpy(note, "PN532 not found-check wiring/DIP");
  else if (!sdOK)   strcpy(note, "WARNING: no SD card");
  else              snprintf(note, sizeof(note), "%d in roster", rCount);
  drawStatus(nfcOK ? "Ready" : "Reader?", note,
             nfcOK ? (sdOK ? TFT_GREEN : TFT_ORANGE) : TFT_RED);
  drawTopBar(true);                          // paint the clock/WiFi bar right away
  tone(SPEAKER_PIN, 1200, 80);               // boot blip
  Serial.println("Serial commands: dump | roster | upload | count | help");
}

// --------------------------------- loop -------------------------------------
void loop() {
  handleSerial();                            // USB commands: dump the SD files, etc.
  wifiDiagTick();                            // DEBUG: report WiFi/NTP progress over serial

  static unsigned long lastBar = 0;          // refresh the clock/WiFi bar once a second
  if (millis() - lastBar >= 1000) { lastBar = millis(); drawTopBar(); }

  // clear the result back to "Ready" on a timer — no blocking delay
  if (showingResult && (long)(millis() - resultUntil) >= 0) {
    drawStatus("Ready", "tap your card", TFT_GREEN);
    showingResult = false;
  }
  if (!nfcOK) { delay(200); return; }

  uint8_t uid[7]; uint8_t len = 0;
  if (nfc.readPassiveTargetID(PN532_MIFARE_ISO14443A, uid, &len, 300)) {
    char id[15]; uidToKey(uid, len, id);      // 10-digit card id (never stored)
    unsigned long now = millis();
    if (strcmp(id, lastUid) == 0 && (now - lastTagTime) < COOLDOWN_MS) return;
    strncpy(lastUid, id, 15);  lastUid[14] = 0;
    lastTagTime = now;

    char token[33]; computeToken(KMAC, id, token);  // keyed one-way token
    const Entry* e = lookupToken(token);
    char name[40];
    bool known = (e != NULL) && decryptName(e->enc, name, sizeof(name));
    Serial.printf("Card token %s -> %s\n", token, known ? name : "UNKNOWN");

    logToSD(token);                           // attendance stores timestamp + token (local, no cloud)

    if (known) { beepKnown();   drawStatus(name, sdOK ? "saved" : "no SD", TFT_CYAN); }
    else       { beepUnknown(); drawStatus("Unknown", "not registered", TFT_ORANGE); }
    resultUntil = now + RESULT_MS;
    showingResult = true;
  }
}

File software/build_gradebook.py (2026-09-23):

#!/usr/bin/env python3
"""
Fill a Canvas gradebook attendance column from the reader's SD log.

Runs on your laptop (which has secret.key). It decrypts each logged token -> the AndrewID
typed at registration, matches that AndrewID to a Canvas student by SIS Login ID, decides
Present/Late/Absent from the tap time, and writes a Canvas-importable CSV with just the one
attendance column filled. Absent = 0.

Older rosters that stored a typed name still work: matching falls back to name
comparison (and the --aliases file) when a value isn't an AndrewID.

Inputs
  --canvas     Canvas gradebook export CSV (required)
  --attendance device log 'timestamp,token' (default attendance.csv)
  --roster     encrypted roster 'token,enc' (default roster.csv)
  --key        secret.key (default secret.key)
  --aliases    name/ID fixups 'typed_value,sis_login_id' (default aliases.csv, optional)
  --registration-log
               registration_log.csv 'timestamp,token' (default registration_log.csv,
               optional). A student who registered a card that day but never tapped
               (reader wasn't set up yet, e.g.) is credited as present/late from
               their registration time instead of being marked absent.
Session
  --date       session date YYYY-MM-DD (required)
  --start      class start HH:MM 24h (required)
  --late-after minutes after start still counted on-time  (default 10)
  --close      minutes after start after which it's absent (default 30)
  --late-frac  fraction of points for a late tap          (default 0.5)
  --column     Canvas assignment column to fill, e.g. "Aug 25 Activity" (required)
  --out        output CSV (default <canvas>_filled.csv)

Requires:  pip install cryptography
Example:
  python3 build_gradebook.py --canvas Grades.csv --attendance att.csv \
      --date 2026-08-25 --start 10:00 --late-after 10 --close 30 \
      --late-frac 0.5 --column "Aug 25 Activity"

Structure: parse_args() -> build() -> Result; render_report() + write_output().
build() does all the file reading and the matching/scoring; it raises SystemExit
on bad input (missing files, unusable Canvas CSV, unresolvable --column) exactly
as the script always has. main() is the thin CLI wrapper.
"""
import csv, os, re, sys, argparse
from dataclasses import dataclass, field
from datetime import datetime

import attendance_crypto as ac


# ------------------------------- helpers ------------------------------------
def norm_tokens(s):
    """Canonical name form: lowercase alpha/num tokens, sorted (order-independent)."""
    s = re.sub(r"[^a-z0-9 ]", " ", (s or "").lower())
    return tuple(sorted(t for t in s.split() if t))


def fmt_points(x):
    if abs(x - round(x)) < 1e-9:
        return str(int(round(x)))
    return ("%.4f" % x).rstrip("0").rstrip(".")


def col_label(h):
    """Header 'Jan 20 Activity (995978)' -> 'jan 20 activity' for matching."""
    return re.sub(r"\s*\(\d+\)\s*$", "", h or "").strip().lower()


def load_token_names(K, roster_path):
    names = {}
    if not os.path.exists(roster_path):
        sys.exit(f"Missing {roster_path}")
    with open(roster_path, newline="", encoding="utf-8") as f:
        for row in csv.reader(f):
            if not row or len(row[0].strip()) != 32:
                continue
            try:
                names[row[0].strip()] = ac.decrypt_name(K, row[1].strip())
            except Exception:
                names[row[0].strip()] = "(decrypt failed)"
    return names


def load_aliases(path):
    """{norm_tokens(typed_value): sis_login_lower}"""
    m = {}
    if path and os.path.exists(path):
        with open(path, newline="", encoding="utf-8") as f:
            for row in csv.reader(f):
                if not row or len(row) < 2 or row[0].strip().lower() in ("", "typed_name", "typed_value"):
                    continue
                m[norm_tokens(row[0])] = row[1].strip().lower()
    return m


# --------------------------- Canvas CSV parsing ---------------------------
@dataclass
class CanvasIndex:
    """A parsed Canvas export: the raw rows plus the lookups build() needs."""
    header: list
    points_row: list
    rows: list                       # every row of the CSV, mutated in place on fill
    c_student: int
    c_login: int
    student_rows: list               # row indices that look like enrolled students
    by_login: dict                   # sis_login_lower -> row index
    by_andrew: dict                  # andrew_id_lower (SIS login local-part) -> [row indices]
    by_norm: dict                    # norm_tokens(student name) -> [row indices]


def parse_canvas(path):
    with open(path, newline="", encoding="utf-8") as f:
        rows = list(csv.reader(f))
    if len(rows) < 3:
        sys.exit("Canvas CSV looks empty.")
    return rows


def _canvas_col_index(header, name):
    for i, h in enumerate(header):
        if h.strip().lower() == name.lower():
            return i
    sys.exit(f"Canvas CSV has no '{name}' column.")


def _find_points_row(rows, c_student):
    """Index of the 'Points Possible' row. Usually rows[1], but some Canvas
    exports insert an extra posting-policy row ('Manual Posting' etc.) between
    the header and it, so scan for it instead of assuming a fixed offset."""
    for i in range(1, len(rows)):
        if len(rows[i]) > c_student and rows[i][c_student].strip().lower() == "points possible":
            return i
    return 1                                    # fallback: classic 2-row header


def build_index(rows):
    header = rows[0]
    c_student = _canvas_col_index(header, "Student")
    c_login = _canvas_col_index(header, "SIS Login ID")
    points_idx = _find_points_row(rows, c_student)
    points_row = rows[points_idx]

    # student rows = rows with an email in SIS Login ID
    student_rows = [i for i in range(points_idx + 1, len(rows))
                    if len(rows[i]) > c_login and "@" in rows[i][c_login]]
    by_login, by_andrew, by_norm = {}, {}, {}
    for i in student_rows:
        login = rows[i][c_login].strip().lower()
        by_login[login] = i
        local = login.split("@", 1)[0]
        if local:
            by_andrew.setdefault(local, []).append(i)
        by_norm.setdefault(norm_tokens(rows[i][c_student]), []).append(i)
    return CanvasIndex(header, points_row, rows, c_student, c_login,
                       student_rows, by_login, by_andrew, by_norm)


def resolve_column(index, column):
    """Return the target column index for --column, or SystemExit if it can't."""
    want = column.strip().lower()
    matches = [i for i, h in enumerate(index.header) if col_label(h) == want]
    if not matches:
        matches = [i for i, h in enumerate(index.header) if want in col_label(h)]
    if len(matches) == 0:
        sys.exit(f"No assignment column matches '{column}'.")
    if len(matches) > 1:
        opts = ", ".join(index.header[i] for i in matches)
        sys.exit(f"'{column}' is ambiguous; matches: {opts}")
    return matches[0]
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

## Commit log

2026-08-26 Initial commit: NFC Attendance Reader
    Classroom attendance via NFC card tap: ESP32 (CYD) + PN532 reader logs to SD,
    laptop-side Python registers cards and builds a Canvas gradebook import. Card
    numbers and names are never stored in plain text (HMAC token + AES-256).
    [case_body.stl, case_lid.stl, case_stand.stl]
2026-08-26 Add sample Canvas export CSV for trying build_gradebook.py without a real course
    Verified the full software pipeline end-to-end from a clean clone: key
    generation, registration, tap logging, decode, and gradebook scoring
    (present/late/absent, unmatched-name reporting, aliases.csv fixups) all work
    using only the shipped .example templates.
2026-08-28 Add pytest suite, CI, and firmware crypto extraction
    Brings the project under automated test (~190 tests, ~2s, no hardware) with
    99% line coverage of software/ and a 95% gate.
    Tooling
    - pyproject.toml pytest config (pythonpath=software), .coveragerc, requirements
    files (software/, dev, case/), GitHub Actions on Python 3.11-3.14 plus
    case-geometry and non-blocking arduino-compile jobs.
    Tests
    - Crypto: known-answer vectors, round-trips, key handling, PKCS7 edges; a
    contract test binding tests/fixtures/crypto_vectors.json to the firmware
    self-test literals both directions.
    - Gradebook: name matching, Present/Late/Absent scoring, column resolution,
    output integrity, date filtering, r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
    [Grades.csv, Grades_filled.csv, aliases.csv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]
2026-08-28 Add help command and --scan to sd_upload.py
    sd_upload.py now accepts a plain `help` argument that prints full usage,
    and `--scan` lists the serial devices connected right now, flagging the
    one auto-detect would pick. Formatting is a pure describe_ports() helper
    with unit coverage.
2026-08-28 Throttle sd_upload.py payload to avoid device serial-buffer overrun
    Sending the whole roster in one write overruns the reader's 256-byte
    serial buffer while it streams to SD, silently dropping bytes and
    failing verification ("<<<ERR got X/Y bytes>>>"). Send 128-byte chunks
    with a 20 ms pause so the device drains each chunk before the next.
    [sd_upload.py]
2026-08-28 Add firmware side of roster upload over USB
    recvRoster() handles a new `upload` serial command: the host sends a
    "<length> <checksum>" header then the raw roster.csv bytes, which are
    streamed to /roster.new, verified, and renamed over /roster.csv so a
    dropped connection can't corrupt the live roster. loadRoster() runs
    again so the swap takes effect without a reboot. This is the device
    half of software/sd_upload.py.
    Docs: README quick-start and TESTING_GUIDE both mention sd_upload.py as
    an alternative to pulling the SD card; TESTING.md notes test_sd_upload.py.
    [attendance_reader_PN532.ino]
2026-08-28 Add host<->container serial bridge and a browser desktop
    The board's USB serial port belongs to the host and Docker Desktop won't
    forward it, so software/serial_bridge_host.sh (host) exposes it over TCP
    with socat and software/serial_bridge.sh (container) maps that back to a
    local PTY the Python tools can use via --port. SERIAL_BRIDGE.md documents
    the flow and its limits (flashing still needs the host). .gitignore skips
    the generated software/reader-port symlink.
    devcontainer: add the desktop-lite feature (noVNC on 6080 / VNC on 5901)
    so register_cards.py's tkinter GUI can run, install socat in
    postCreateCommand, and add --add-host=host.docker.internal:host-gateway
    so the bridge resolves on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
2026-08-28 Add WiFi/clock status bar and arduino-cli flash tooling
    Firmware: drawTopBar() paints a 26px band above drawStatus()'s center
    band -- NTP clock on the left ("clock not set" until WiFi+NTP sync),
    "WiFi"/"no WiFi" on the right. Painted once at boot and refreshed once a
    second from loop(); each half only redraws when its text changes.
    flash.sh: compile + upload with arduino-cli (port auto-detect, 115200
    for the CH340, -n for a compile-only check, guards on missing core).
    setup-arduino.sh: install arduino-cli + the ESP32 core + libraries,
    then drop the ~1.5 GB download staging cache.
    devcontainer: install the arduino-cli binary on create and cache
    ~/.arduino15 + ~/Arduino on volumes so a rebuil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
    [attendance_reader_PN532.ino]
2026-08-28 Register AndrewIDs instead of names; match gradebook by SIS Login ID
    Registration now prompts for a 3-8 character AndrewID and rejects anything
    outside that range (valid_andrew_id, covered by tests).
    build_gradebook matches each tapped AndrewID to a Canvas student by the
    local-part of SIS Login ID (exact, case-insensitive) via a new by_andrew
    index, checked after aliases and before name matching. Name matching stays
    as a fallback so older name-based rosters keep working. Report wording and
    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
2026-09-23 Reject a card tap typed into the AndrewID field
    The keyboard-wedge reader types the card number + Enter wherever focus
    is. If a student taps a second time while the AndrewID prompt is up
    (because the first tap "didn't seem to work"), the card number was being
    saved as their AndrewID. A real AndrewID always contains a letter, so an
    all-digit entry is now cleared with a message instead of saved.
    [register_cards.py]
2026-09-23 Find Canvas's Points Possible row by label, not position
    Some Canvas exports insert a posting-policy row ("Manual Posting")
    between the header and "Points Possible". build_index assumed
    Points Possible was always rows[1], so it read the wrong points value
    and started scanning for students one row too early. It now scans for
    the row whose Student cell is "Points Possible" and falls back to
    rows[1] if none is found.
    [build_gradebook.py]
2026-09-23 Add recover_sessions.py to date logs from a reader whose clock never synced
    If WiFi/NTP never connects, every tap is logged as
    unsynced-<millis-since-boot> and build_gradebook skips all of them.
    recover_sessions.py splits the log into power-on sessions (millis going
    backwards, or a synced row followed by an unsynced one), prints who
    tapped in each session, and rewrites the rows with a date you supply per
    session (--map N=YYYY-MM-DD). Time of day is the time since the
    session's first tap, so run build_gradebook with --start 00:00 on the
    output.
    Rows with truncated tokens or garbled (NUL-padded) timestamps from torn
    SD writes are reported and dropped. Otherwise a garbled timestamp would
    be re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
    [recover_sessions.py]
2026-09-23 Add temporary WiFi/NTP serial diagnostics to the firmware
    WiFi (and so NTP) still isn't connecting on the classroom network. At
    boot the reader now scans once and prints every visible 2.4 GHz network,
    flagging whether the target SSID is among them. Every 2 s it prints the
    connection status until WiFi and the NTP clock are both up. It prints
    the SSID and the password length only, never the password.
    Watch with: arduino-cli monitor -p <port> -c baudrate=115200
    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
2026-09-23 Pin the desktop-lite devcontainer feature in the lock file
    Follow-up to 9504585, which added the noVNC desktop feature to
    devcontainer.json but not its lock entry.
2026-09-23 recover_sessions: list sessions so the --map dates can be chosen
    The docstring said to pick session dates "from sessionize output", but
    nothing printed the sessions, so the only way to see them was to read
    the code. main() now prints one line per session: tap and card counts,
    the log lines it covers, how long it ran, any synced timestamps inside
    it, and its mapped date. Run once without --map to see the list.
    main() also takes argv, like build_gradebook, and now has tests.
    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
